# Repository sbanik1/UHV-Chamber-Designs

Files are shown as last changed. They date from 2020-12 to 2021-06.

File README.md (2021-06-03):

# UHV-Chamber-Designs
UHV Chamber Designs for Cold Atom Experiments.

## Need for ultra-high vacuum (UHV) for Cold Atom Experiments
The goal of an ultracold atomic physics experiment, is to produce quantum degenrate gases, for observing macroscopic effects of quantum statistics. This is possible when individual atomic wavepackets sufficiently overlap. The extent of these individual atomic wavepackets is given by the thermal de-broglie wavelength .

<p align="center">

</p>

For a given atomic species, the only way to increase  is by reducing the temperature. After the inital pre-cooling stages, the final cooling process for quantum degenerate gas production, is evaporative cooling. Atoms are evaporatively cooled by trapping them in magnetic traps or optical dipole traps. For **effective evaporative cooling**, one requires the collisional re-thermalization time to be much shorter than the lifetime of atoms in the trap [[1]](#1). In free space, atoms collide with background air particles and are ejected from the traps. This problem is solved by maintaing a vacuum of the order of  mbar.

## ErNa Vacuum Chamber Designs
This repo contains solidwork designs of the ErNa UHV chamber. Below are images of the full assembly.

<table>
  <tr>
    <td>
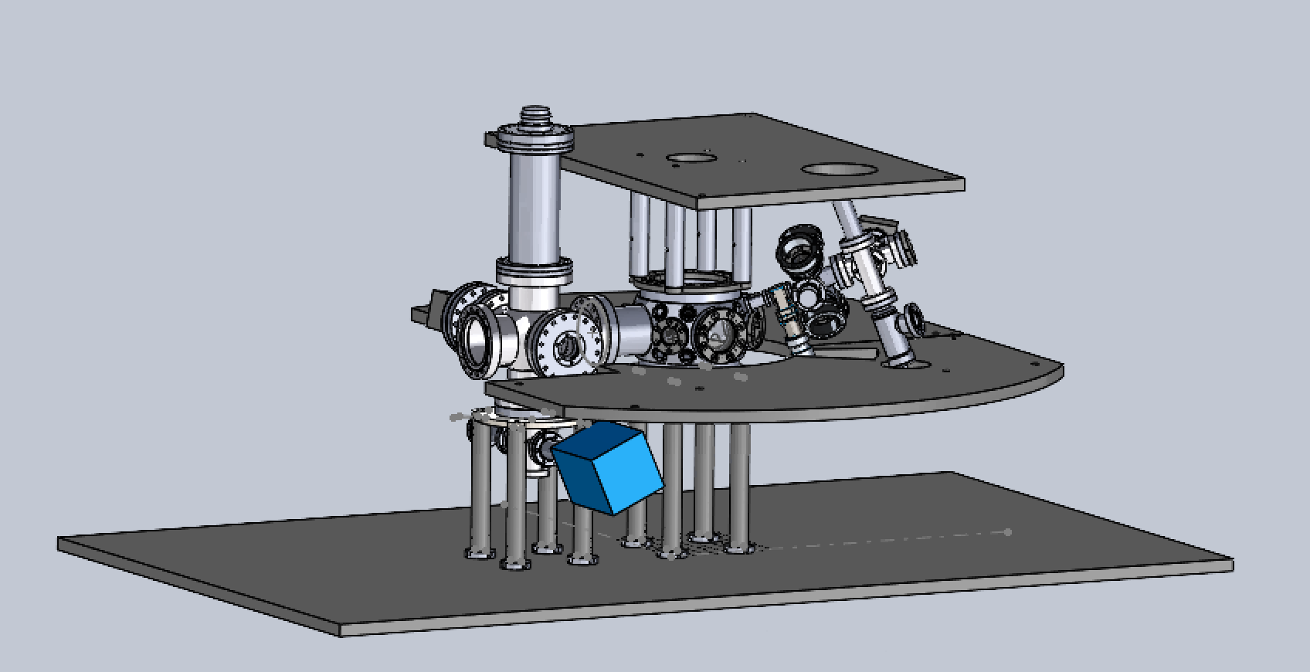
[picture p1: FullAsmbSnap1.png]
      </td>
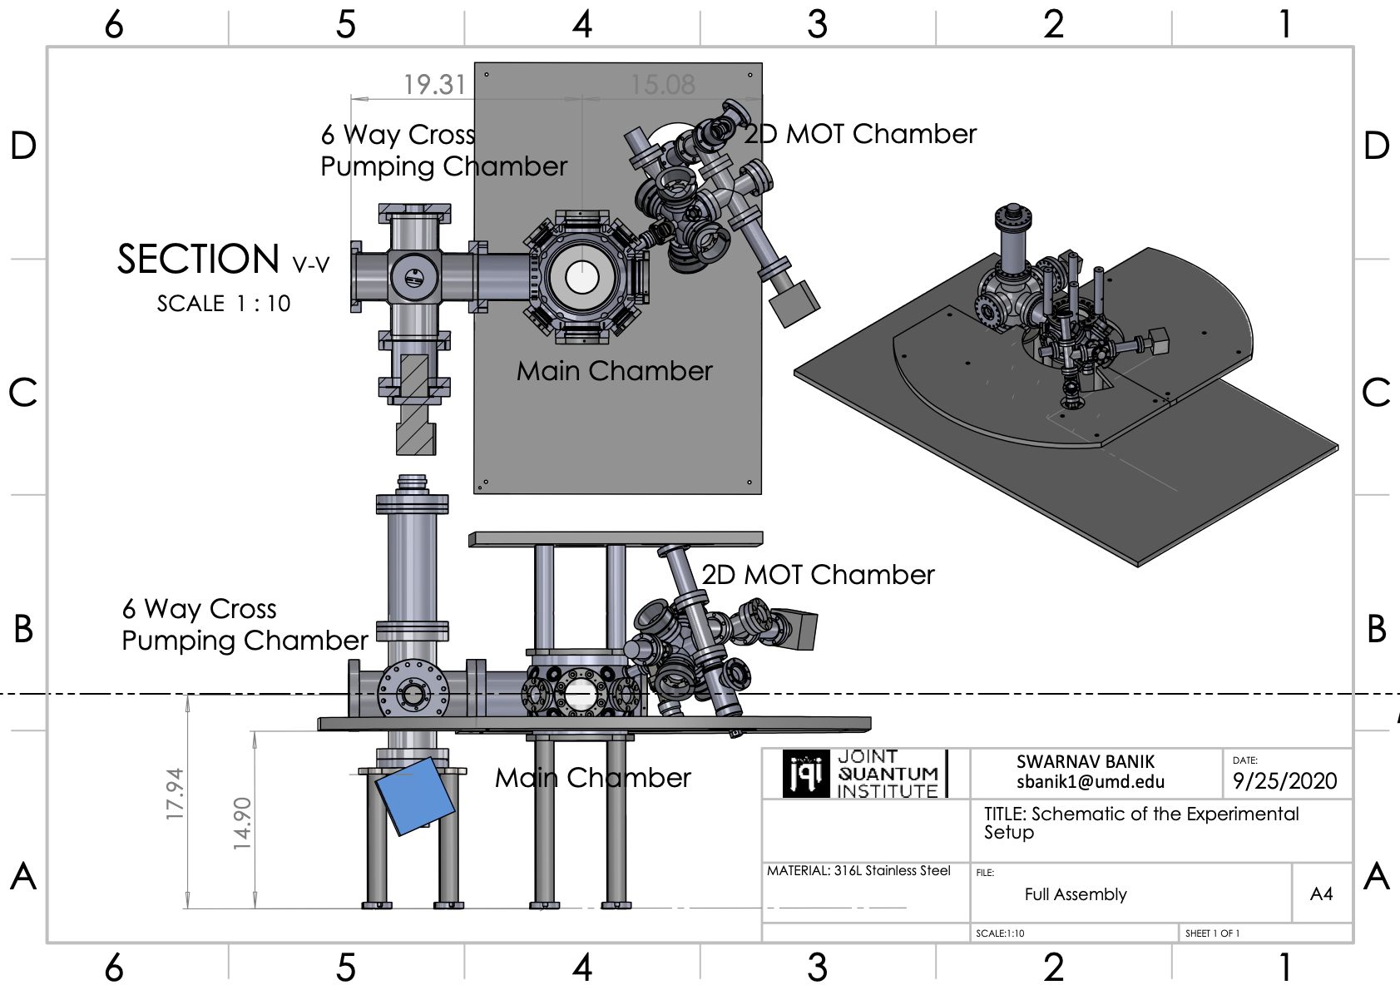
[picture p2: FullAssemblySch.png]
    <td></td>
  </tr>
</table>

### Overview of the different parts
All the science happens in the main chamber where sodium atoms are cooled down to a BEC. The sodium vapour is generated in the 2D MOT chamber where it is pre-cooled before being sent over to the main chamber. The pumping elements for the main chamber are attached to the 6 way cross connected to the main chamber. The main chamber and the 2D MOT are maintained at different pressures. The 2D MOT chamber has the atomic source which needs to heated to high temperatures. As a result, it is not possible to maintain UHV pressures in this chamber. So the 2D MOT chmaber and Main chamber are separated by a differential pumping tube. Below is the schematic of the differential pumping tube used.

<table>
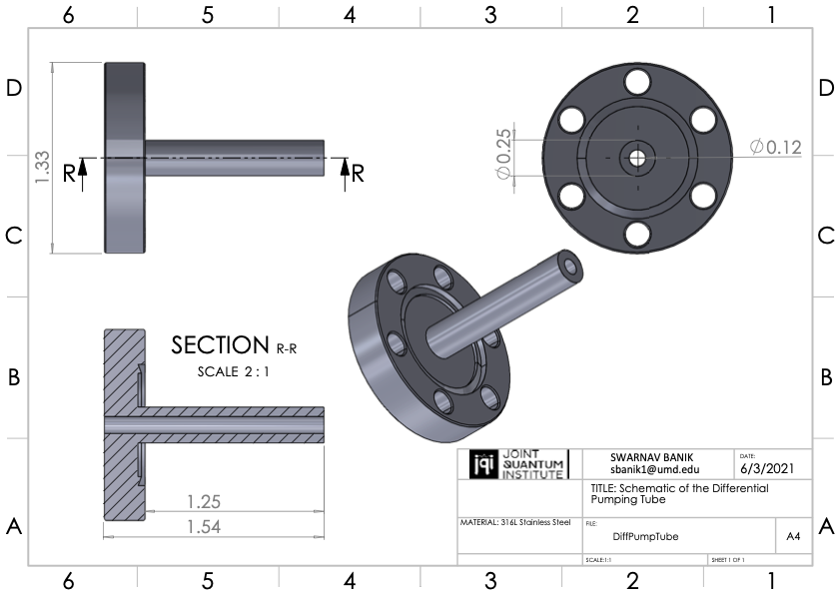
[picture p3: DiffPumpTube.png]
  <tr><td align="center"></td></tr>
</table>

<table>
  <tr>
    <td align="center">
      Main Chamber
    </td>
    <td align="center">
      2D Magneto Optical trap (2D MOT)
    </td>
    <td  align="center">
      6 Way Cross Setup
    </td>
  </tr>
  <tr>
    <td>
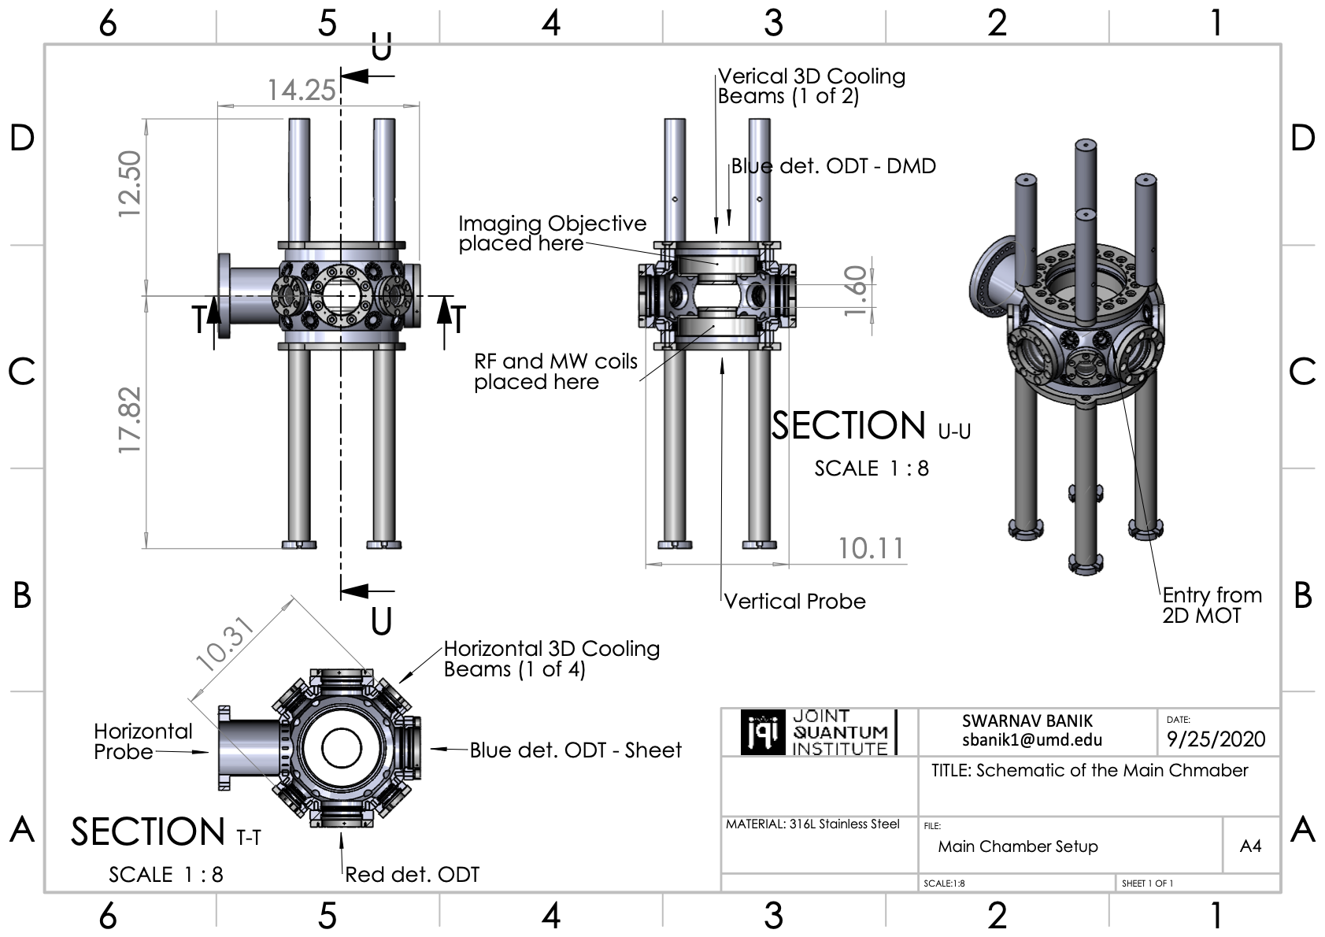
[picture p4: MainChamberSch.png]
      
    </td>
    <td>
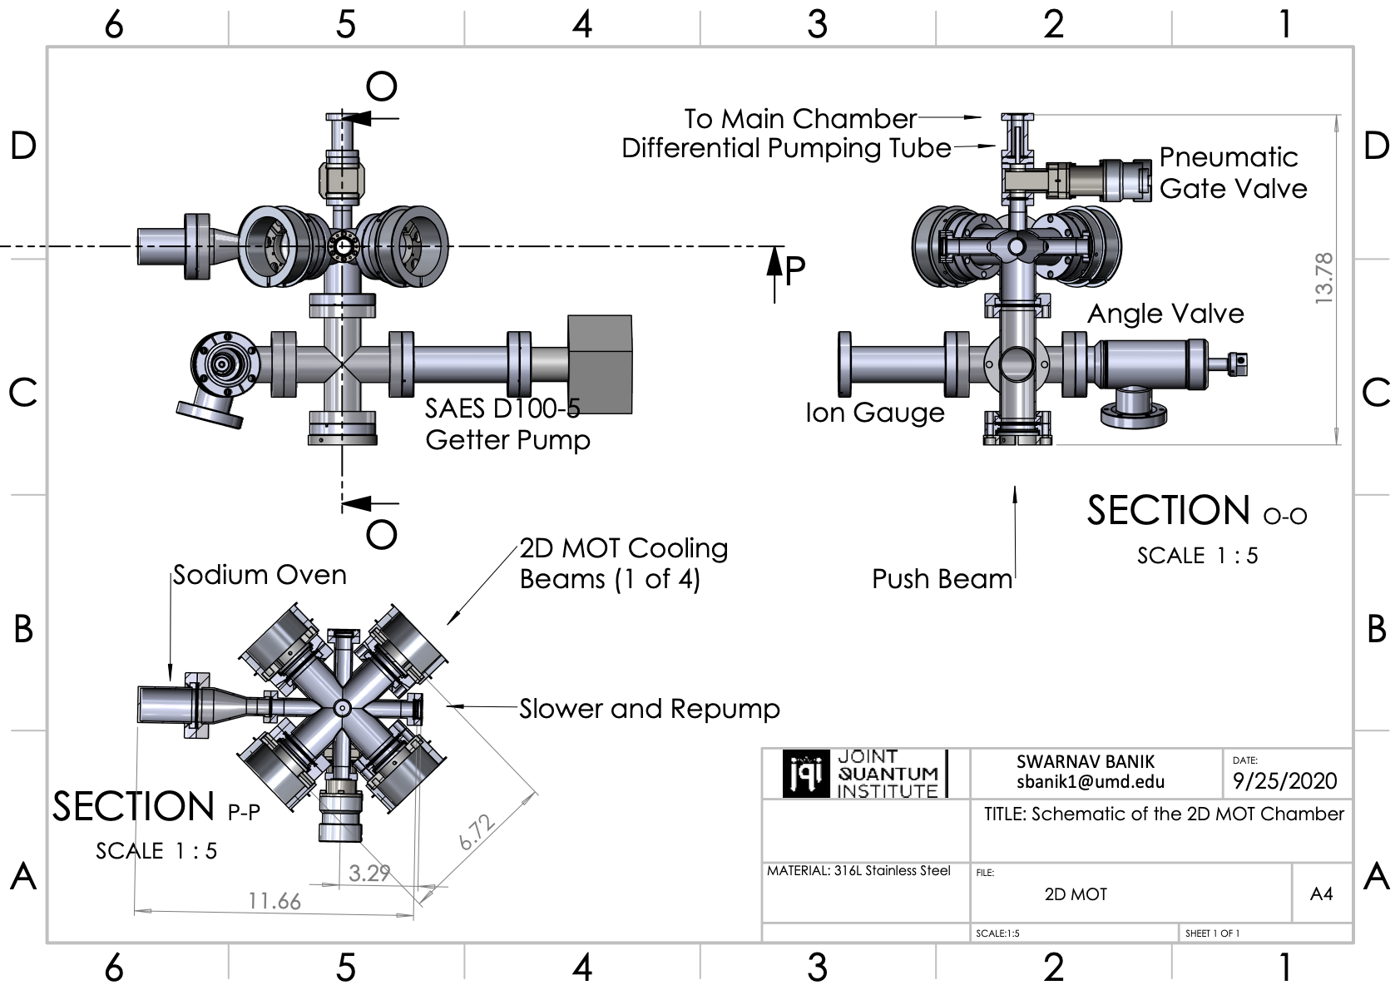
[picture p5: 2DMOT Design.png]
      
    </td>
    <td>
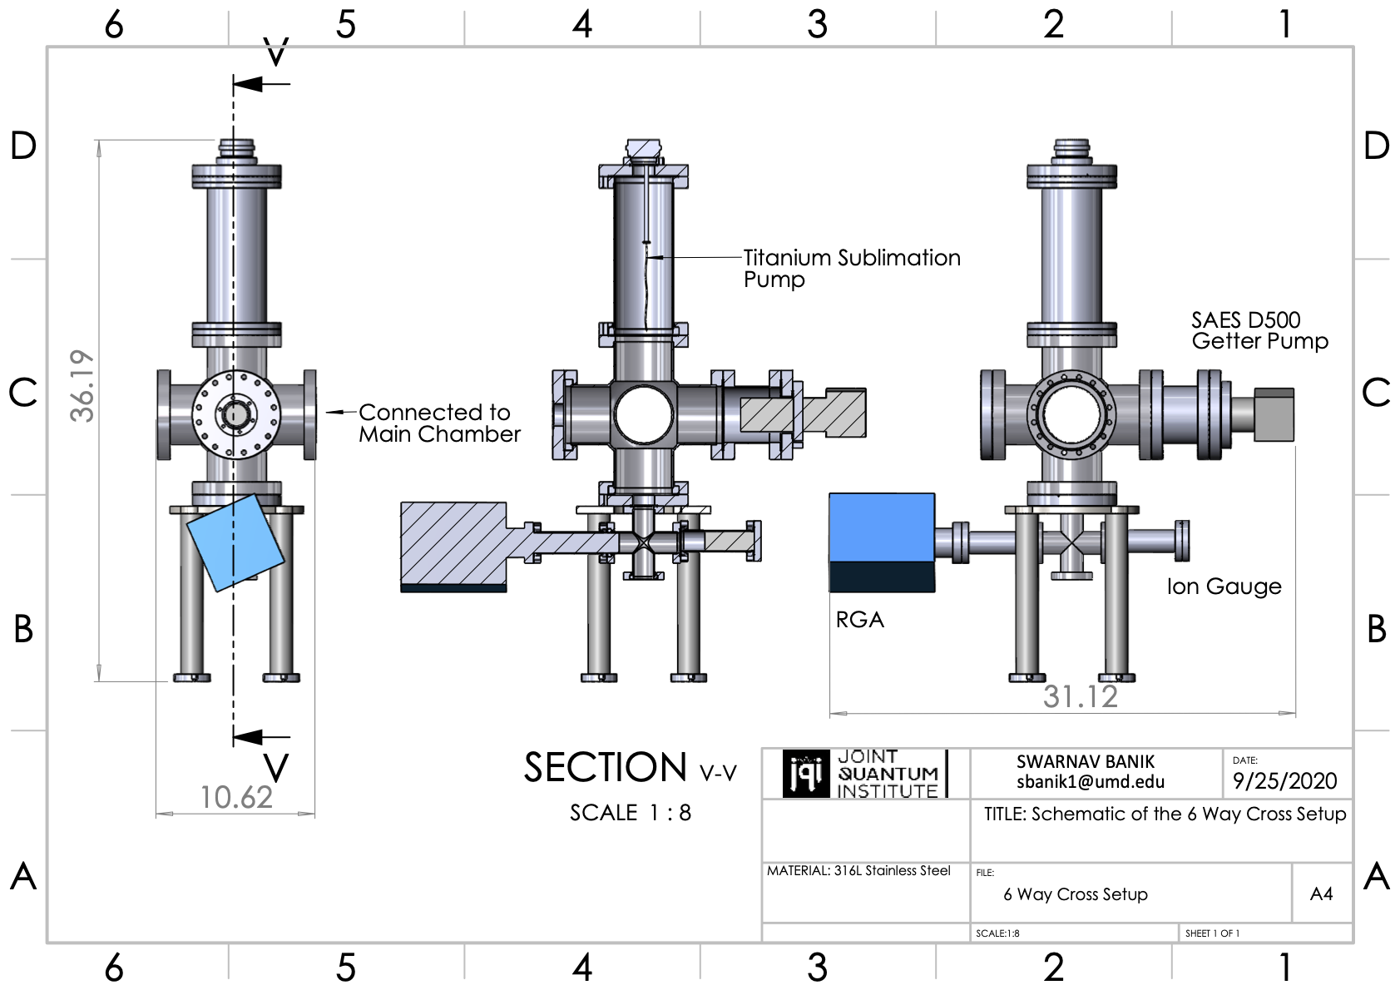
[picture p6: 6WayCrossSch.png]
      
    </td>
  </tr>
</table>

### Improvements from Traditional Zeeman Slowers
<table>
  <tr>
    <td align="center">
      Chamber with Zeeman Slower [2]
    </td>
    <td align="center">
      Chamber with 2D MOT
    </td>
  </tr>
  <tr>
    <td>
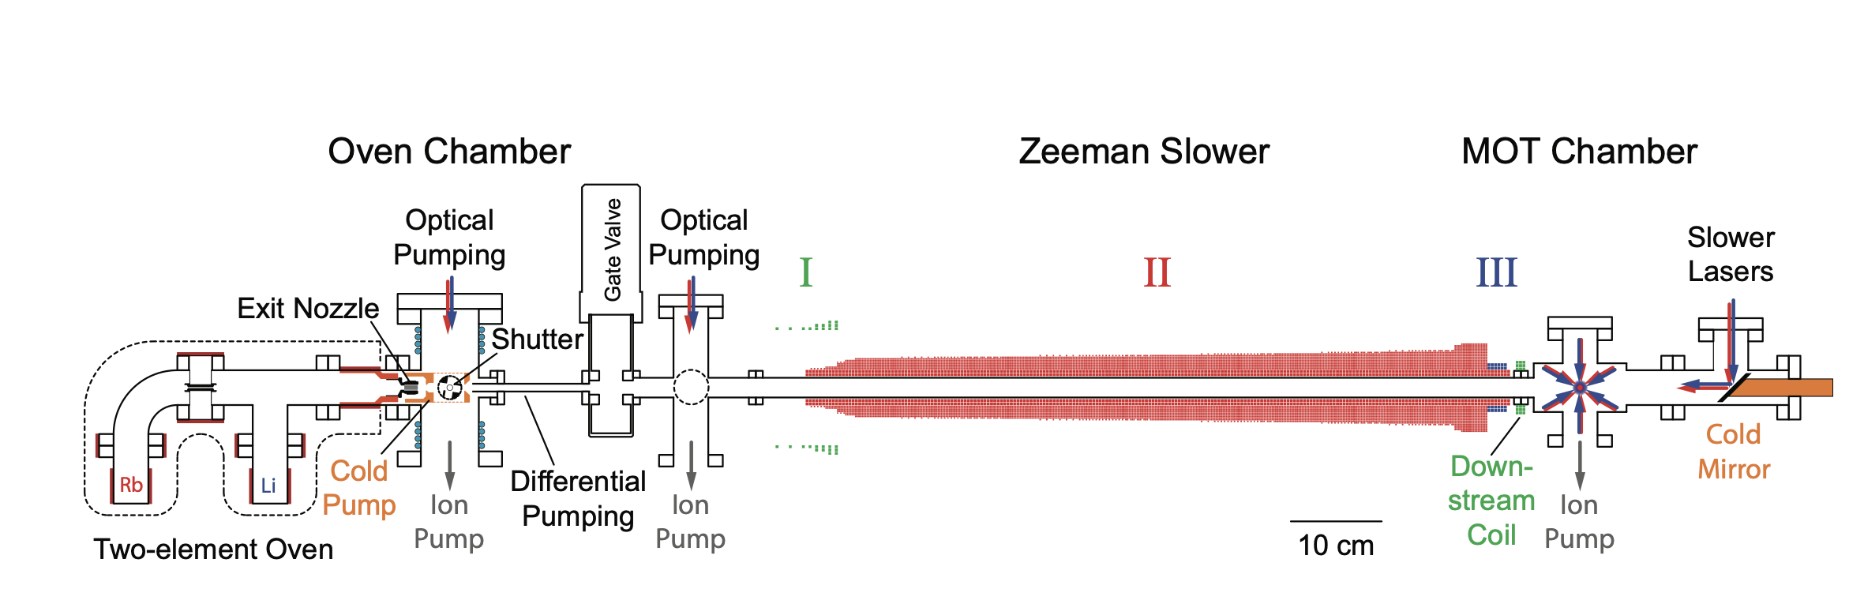
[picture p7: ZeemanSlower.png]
      
    </td>
    <td>
      
    </td>
  </tr>
</table>

The image to the left is a typical Zeeman slower [[2]](#2). Zeeman slowers are about 1m long. Our 2D MOT is atleast 3 times shorter.

## References
<a id="1">[1]</a> 
W. Keterlee, D.S. Durfee, and D.M. Stamper-Kurn (Apr. 5, 1999). 
Making, probing and understanding Bose-Einstein condensates. 
arXiv:cond-mat/9904034v2 

<a id="2">[2]</a> 
G. Edward Marti, Ryan Olf, Enrico Vogt, Anton Öttl, and Dan M. Stamper-Kurn (Apr., 2010). 
Two-element Zeeman slower for rubidium and lithium. 
Phys. Rev. A,81,043424

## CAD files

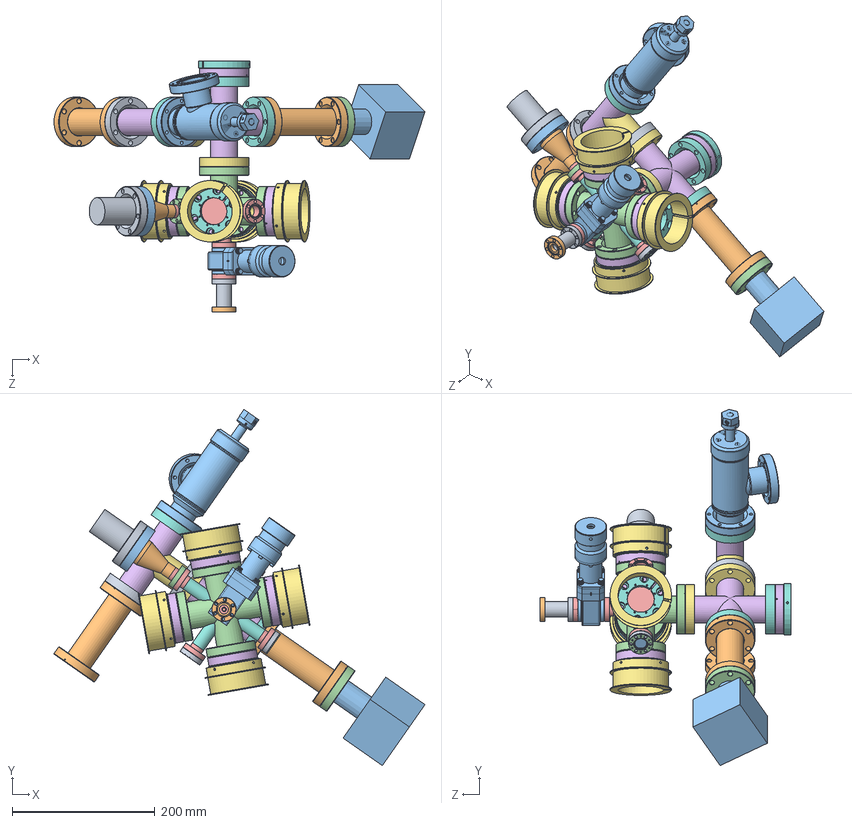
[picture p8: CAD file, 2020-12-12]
2D MOT/2D MOT.SLDASM
518.9 x 498.2 x 351.4 mm
Cup
110014 (2.75 X 1.5 NR)
100004 (1.33 X .75 REC)
100004 (1.33 X .75 INS)
405002 P1_405002-001 x 2
405002 P2_110014 (2.75 X 1.5 NR)_1 x 2
405002 P4_100014 (2.75 X 1.5 REC)_1 x 2
405002 P5_100014 (2.75 X 1.5 INS)_1 x 2
2D MOT nipple_402002 rev A x 2
2D MOT Pump outer
2D MOT Pump conflat_110008
2D MOT Pump inner
404002 P5_404002-001
404002 P6_404002-002
404002 P4_110014 (2.75 X 1.5 NR)_1
404002 P3_100014 (2.75 X 1.5 REC) x 2
404002 P1_100014 (2.75 X 1.5 INS) x 2
Angle Valve_314003
5way MDC-406002-mine
MiniFlange-weld-mine x 5
ChamberTube
CameraTube
OvenTube x 3
Connection Nipple P1_110000
Connection Nipple P2_110000
Gate Valve 302000
2.75 Window P1-1 x 5
2.75 Window P1-2 x 5
2.75 Window P2 x 5
Coil mount x 4
Viewport Washer 2.75 x 5
0784101L x 2
0194307B x 2
1002201A x 2
Viewport Washer 1.33 x 2
DiffPumpTube

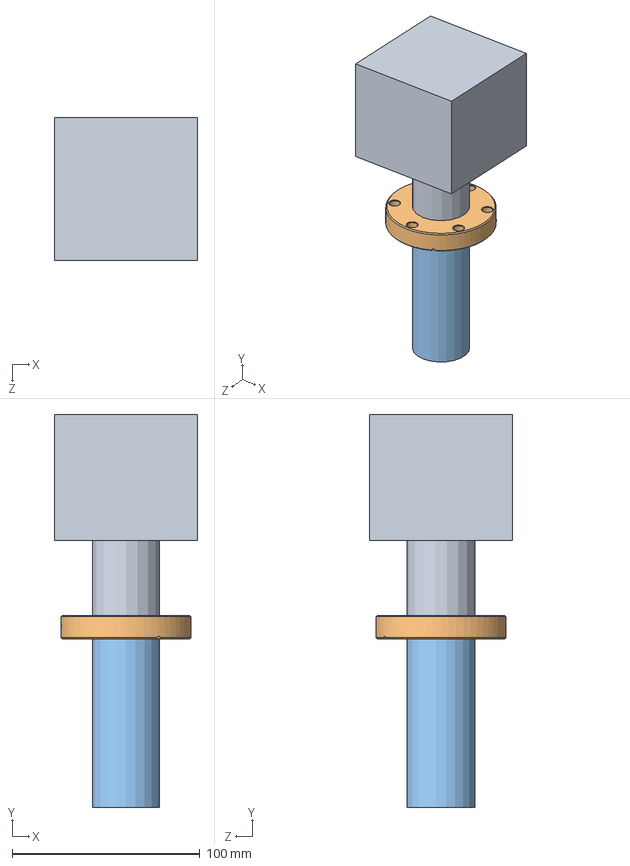
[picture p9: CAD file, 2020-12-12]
2D MOT/SAES Getter_D100-5/2D MOT Pump.SLDASM
76.2 x 209.3 x 76.2 mm
2D MOT Pump outer
2D MOT Pump conflat_110008
2D MOT Pump inner

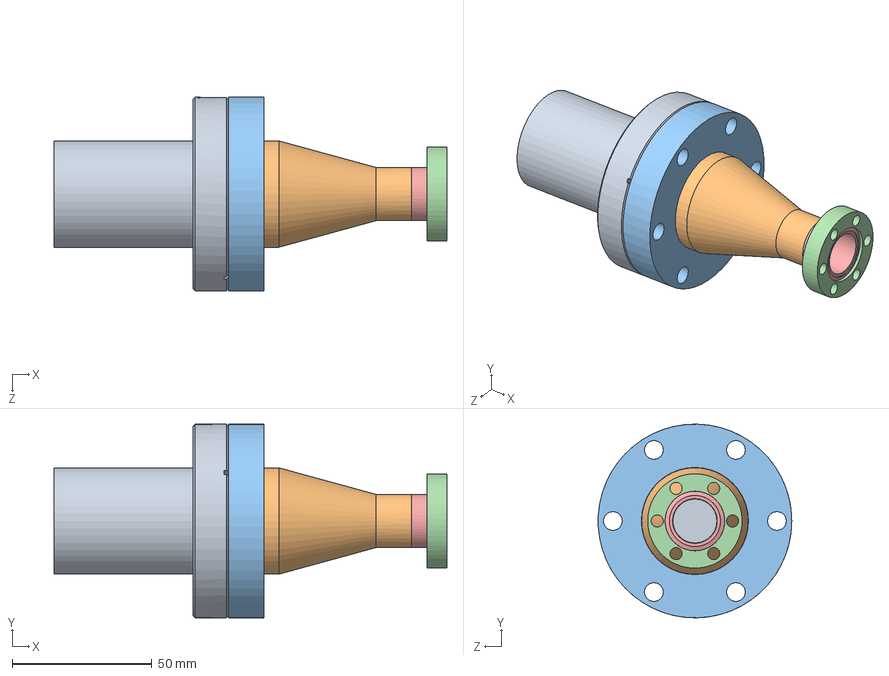
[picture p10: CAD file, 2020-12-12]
2D MOT/Sodium Oven/Na Oven.SLDASM
140.7 x 69.3 x 69.3 mm
Cup
110014 (2.75 X 1.5 NR)
100004 (1.33 X .75 REC)
100004 (1.33 X .75 INS)

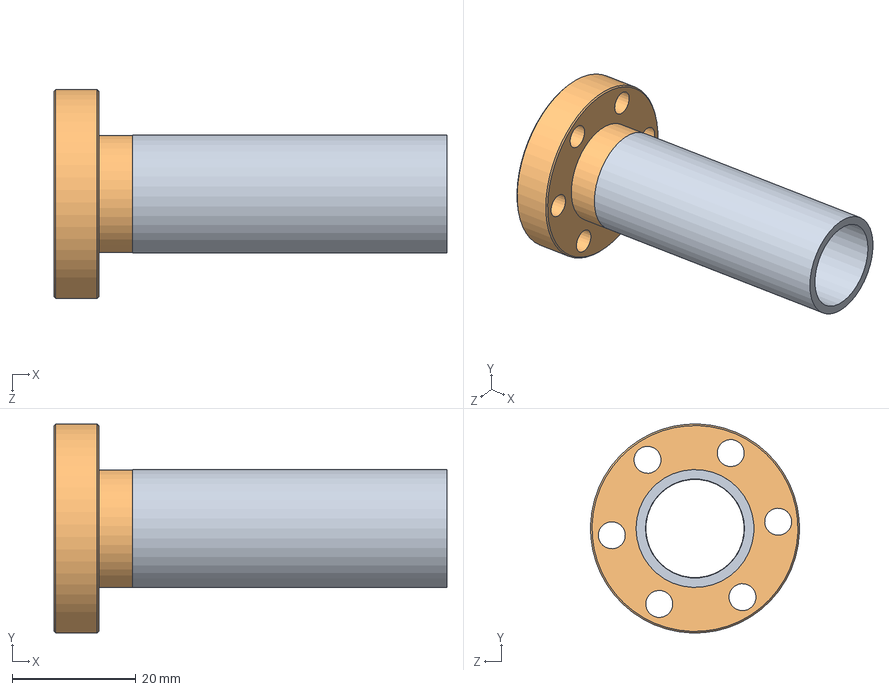
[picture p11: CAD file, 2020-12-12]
2D MOT/Tenway Cross/ Camera Assembly.SLDASM
63.5 x 33.8 x 33.8 mm
CameraTube
MiniFlange-weld-mine

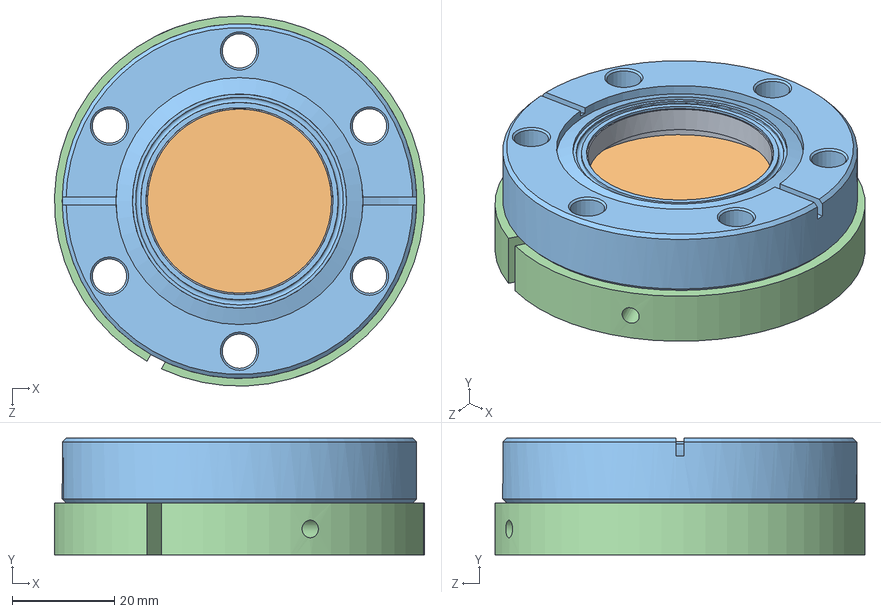
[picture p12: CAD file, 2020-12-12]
Main Chamber/2.75 VP Assembly/2.75 VP Assembly.SLDASM
72.4 x 22.9 x 72.4 mm
2.75 Window P1-1
2.75 Window P1-2
2.75 Window P2
Viewport Washer 2.75

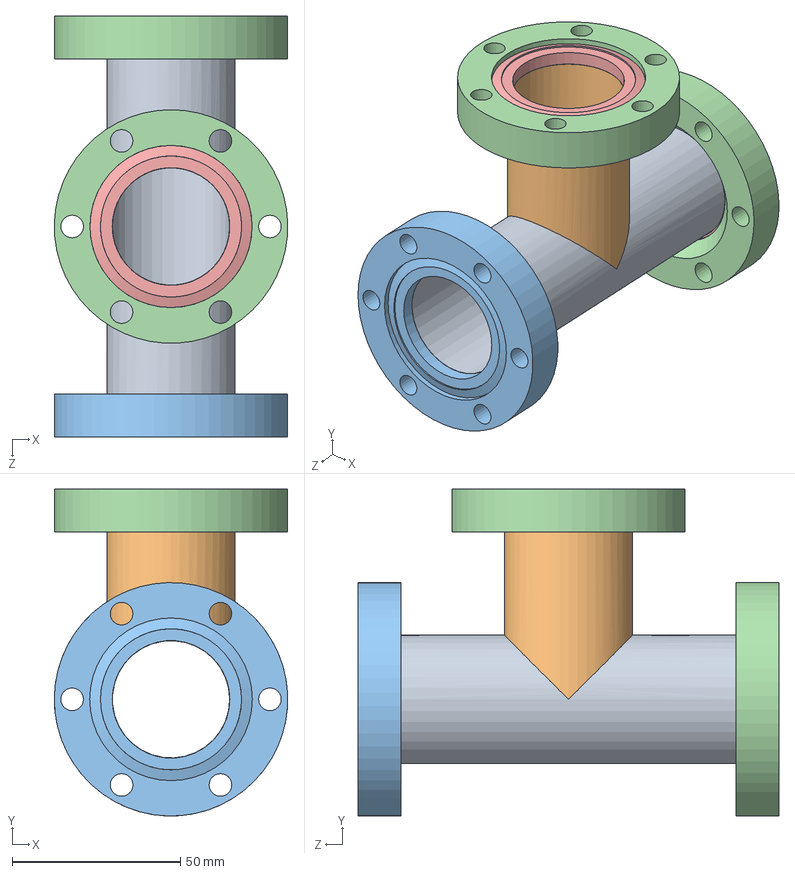
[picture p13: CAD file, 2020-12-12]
Main Chamber/2.75 VP Assembly/2.75 Window/2D MOT tee_404002.SLDASM
69.3 x 97.1 x 124.9 mm
404002 P5_404002-001
404002 P6_404002-002
404002 P4_110014 (2.75 X 1.5 NR)_1
404002 P3_100014 (2.75 X 1.5 REC) x 2
404002 P1_100014 (2.75 X 1.5 INS) x 2

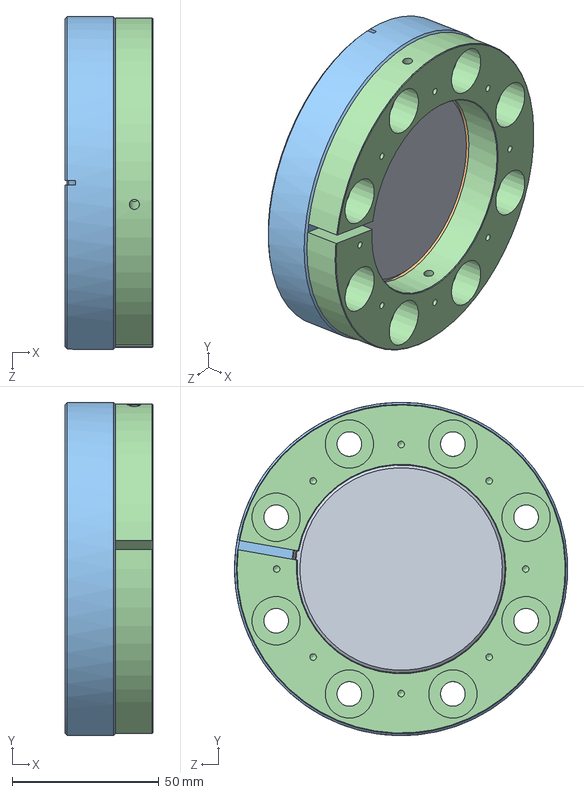
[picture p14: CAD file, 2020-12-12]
Main Chamber/4.5 VP Assembly/4.5 VP Assembly.SLDASM
30.0 x 113.5 x 113.4 mm
1002203A
Viewport 4.5 P1_0194302B
Viewport 4.5 P2_0194603B
Viewport Washer 4.5

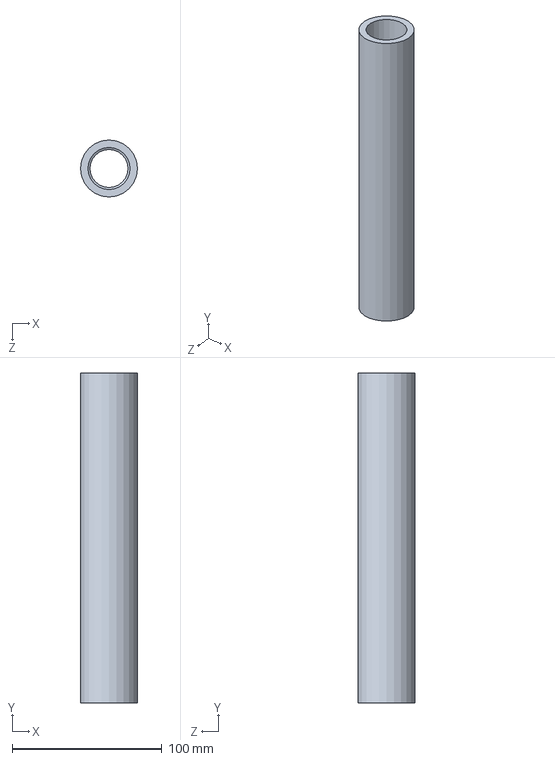
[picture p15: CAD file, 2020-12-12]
Main Chamber/Damped Post Main Chamber/Damped Post for Main Chamber Top P1.SLDPRT
38.1 x 220.5 x 38.1 mm

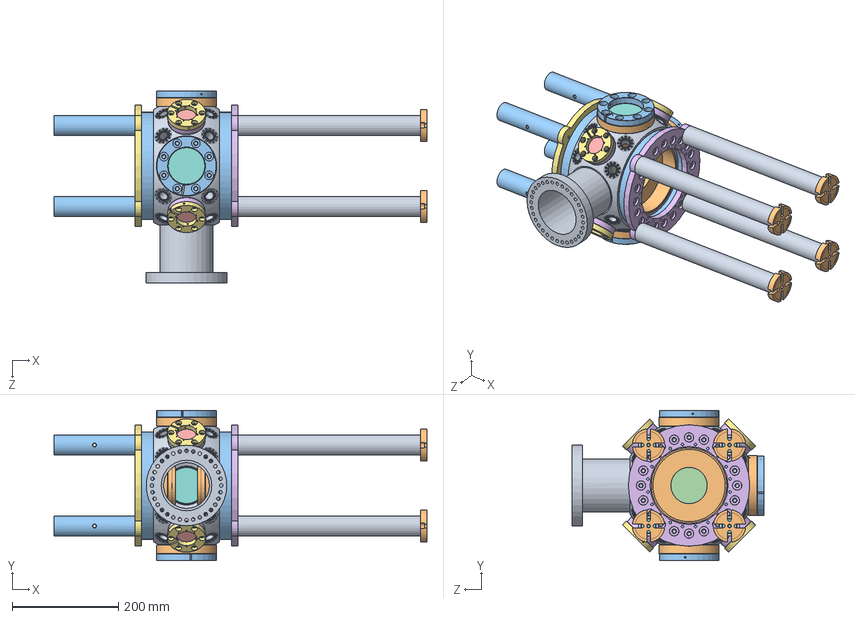
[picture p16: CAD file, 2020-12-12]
Main Chamber/Main Chamber Setup.SLDASM
702.1 x 283.0 x 362.2 mm
Modified Kimball Chamber
ISAdaptor x 2
ISFlange x 2
ISWindow x 2
RecessedRing x 2
Washer Chamber Base
Washer Chamber Top
Damped Post for Main Chamber P2_90322A235 x 8
Damped Post for Main Chamber Bottom P1 x 4
Damped Post for Main Chamber P3_PB2 x 4
Chamber Top Post_P6 x 4
2.75 Window P1-1 x 4
2.75 Window P1-2 x 4
2.75 Window P2 x 4
Viewport Washer 2.75 x 4
1002203A x 3
Viewport 4.5 P1_0194302B x 3
Viewport 4.5 P2_0194603B x 3
Viewport Washer 4.5 x 3

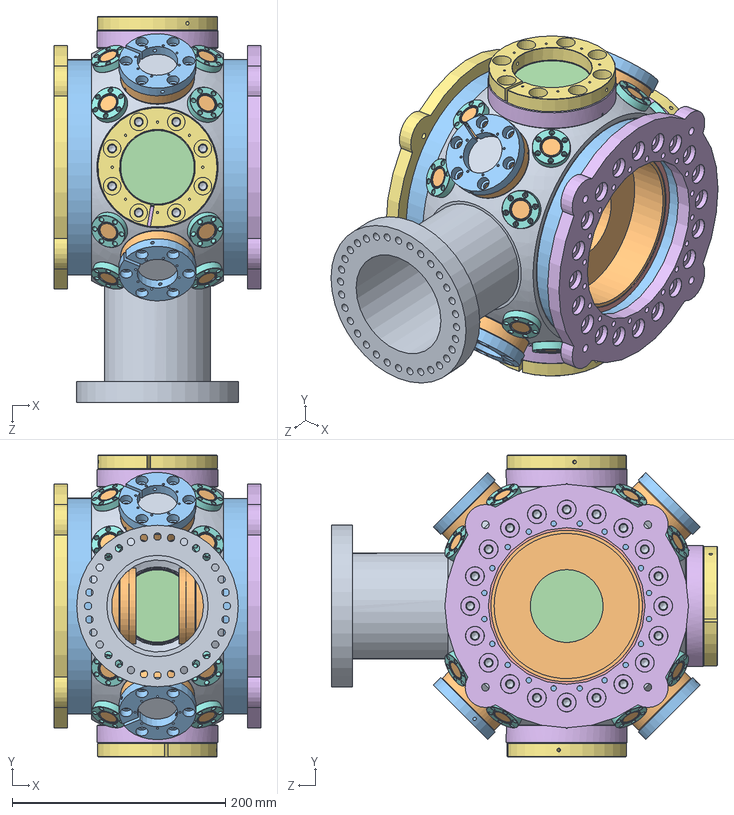
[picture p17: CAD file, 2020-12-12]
Main Chamber/VP distances/Main Chamber VP only .SLDASM
194.1 x 283.0 x 362.2 mm
Modified Kimball Chamber
ISAdaptor x 2
ISFlange x 2
ISWindow x 2
RecessedRing x 2
Washer Chamber Base
Washer Chamber Top
2.75 Window P1-1 x 4
2.75 Window P1-2 x 4
2.75 Window P2 x 4
Viewport Washer 2.75 x 4
1002203A x 3
Viewport 4.5 P1_0194302B x 3
Viewport 4.5 P2_0194603B x 3
Viewport Washer 4.5 x 3
0784101L x 16
0194307B x 16
1002201A x 16

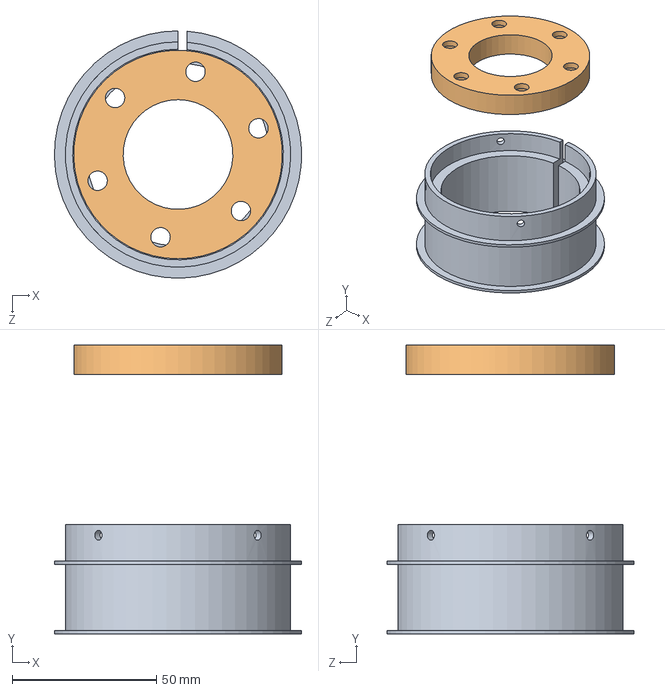
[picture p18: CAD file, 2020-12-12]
2D MOT/2DMOT Bias Coils/Assembly.SLDASM
85.8 x 100.3 x 85.8 mm
Coil mount
Viewport Washer 2.75

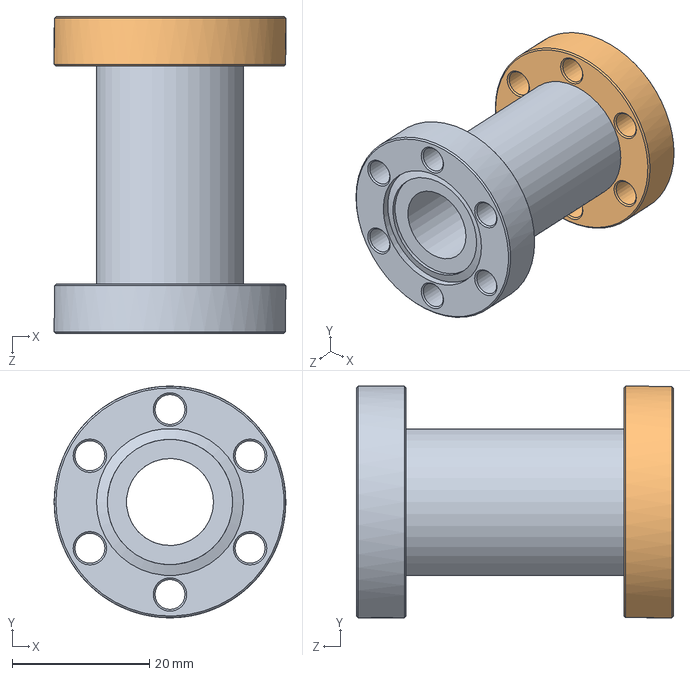
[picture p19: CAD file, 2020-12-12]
2D MOT/Connection nipple/Connection Nipple.SLDASM
33.8 x 33.8 x 46.2 mm
Connection Nipple P1_110000
Connection Nipple P2_110000

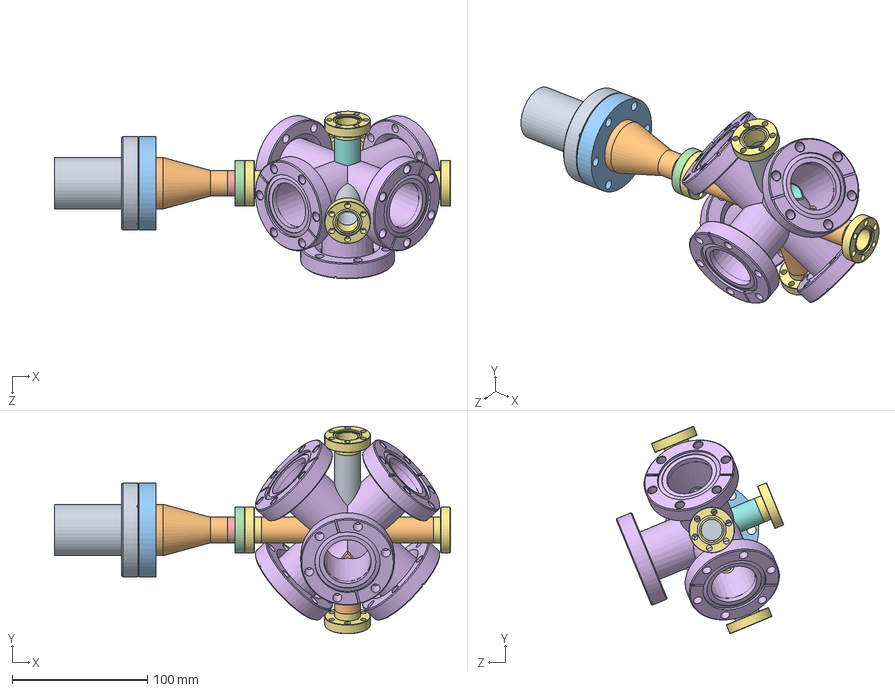
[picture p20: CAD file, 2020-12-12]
2D MOT/Tenaway with Na Oven.SLDASM
293.1 x 153.5 x 124.0 mm
Cup
110014 (2.75 X 1.5 NR)
100004 (1.33 X .75 REC)
100004 (1.33 X .75 INS)
5way MDC-406002-mine
MiniFlange-weld-mine x 5
ChamberTube
CameraTube
OvenTube x 3

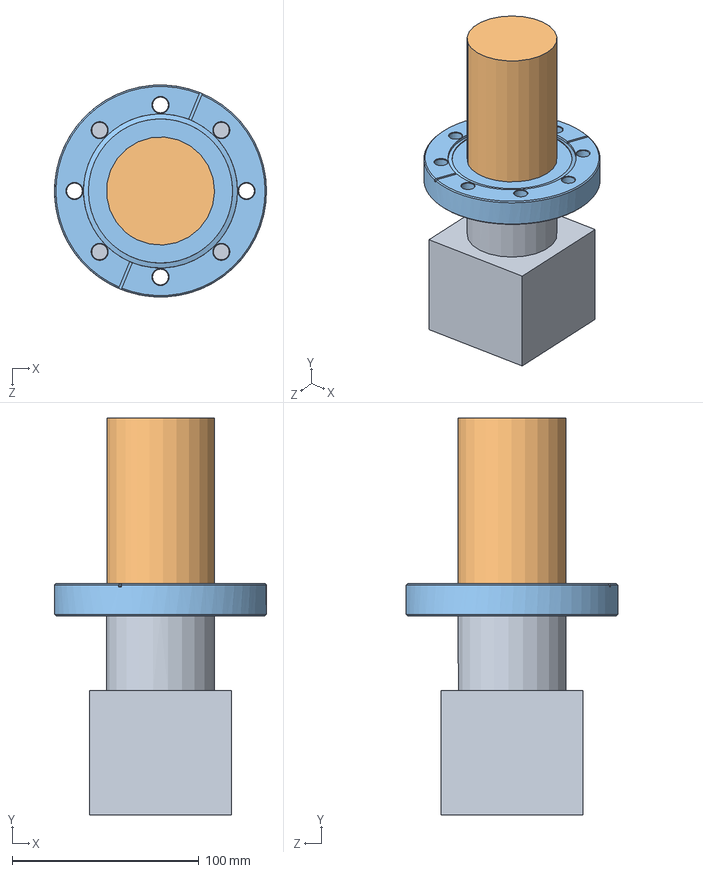
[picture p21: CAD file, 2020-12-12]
6 Way Cross Setup/6 Way Cross Getter SAES D-500/6WayPump.SLDASM
113.5 x 212.6 x 113.5 mm
6WayPump outer
6WayPump inner
6WayPump conflat

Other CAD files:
6 Way Cross Setup/6 way cross setup.SLDASM
Main Chamber/Bucket Window/Bucket Window.SLDASM
Main Chamber/Mini lens stack holder/1.33 Viewport/1.33 Viewport.SLDASM
2D MOT/Conical Adapter 1.33-2.75/Conical Adapter 1.33-2.75.SLDASM
2D MOT/1.33 Window/0194307B.sldprt
2D MOT/1.33 Window/0784101L.sldprt
2D MOT/1.33 Window/0784301N.sldasm
2D MOT/1.33 Window/1002201A.sldprt
2D MOT/1.33 Window/9722013.STEP
2D MOT/1.33 Window/VP_1.33.SLDASM
2D MOT/2.75 Four Way Cross/2.75 Four Way Cross.SLDASM
2D MOT/2.75 Four Way Cross/405002 P1_100014 (2.75 X 1.5 INS).sldprt
2D MOT/2.75 Four Way Cross/405002 P1_405002-001.sldprt
2D MOT/2.75 Four Way Cross/405002 P2_100014 (2.75 X 1.5 R).sldasm
2D MOT/2.75 Four Way Cross/405002 P2_110014 (2.75 X 1.5 NR)_1.sldprt
2D MOT/2.75 Four Way Cross/405002 P3_100014 (2.75 X 1.5 R)_1.sldasm
2D MOT/2.75 Four Way Cross/405002 P3_100014 (2.75 X 1.5 REC).sldprt
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

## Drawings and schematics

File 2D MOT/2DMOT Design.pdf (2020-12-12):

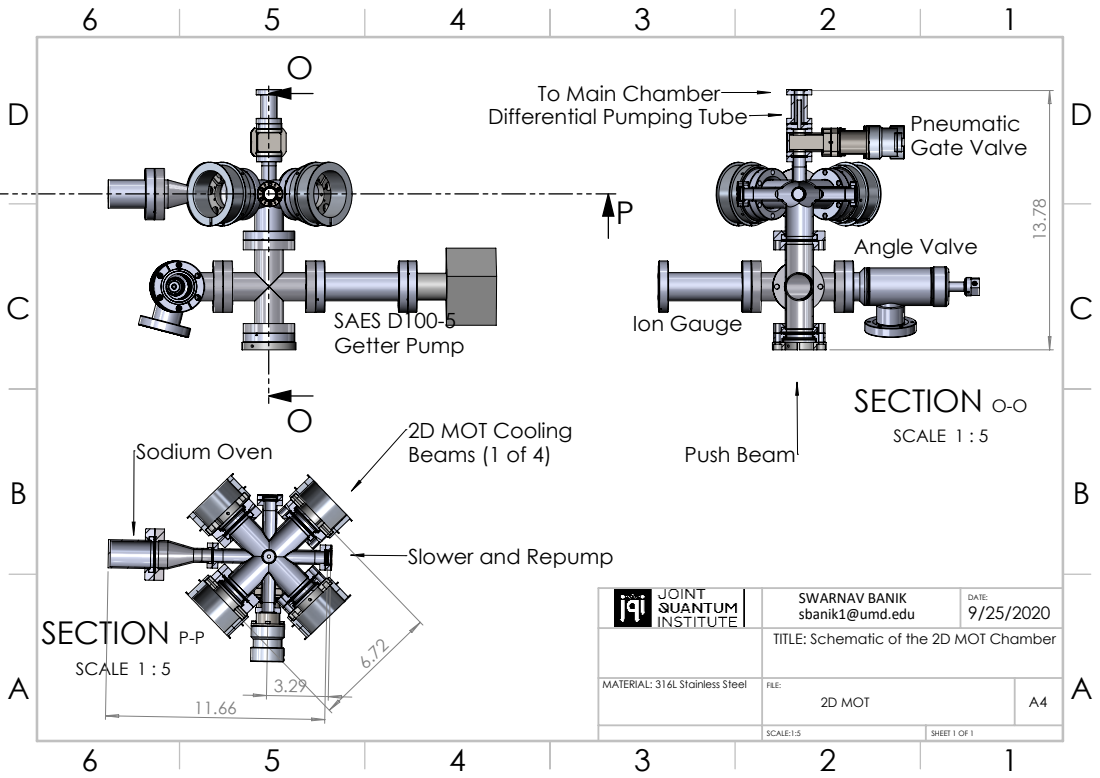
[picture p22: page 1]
SAES D100-5 Getter Pump; SECTION O-O; SCALE 1 : 5; Ion Gauge; Gate Valve; Angle Valve; SECTION P-P; Sodium Oven; Push Beam; 2D MOT Cooling Beams (1 of 4)

To Main Chamber
Differential Pumping Tube

Slower and Repump

SWARNAV BANIK sbanik1@umd.edu | DATE: 9/25/2020

TITLE: Schematic of the 2D MOT Chamber

MATERIAL: 316L Stainless Steel | FILE: 2D MOT | A4

SCALE:1:5 | SHEET 1 OF 1

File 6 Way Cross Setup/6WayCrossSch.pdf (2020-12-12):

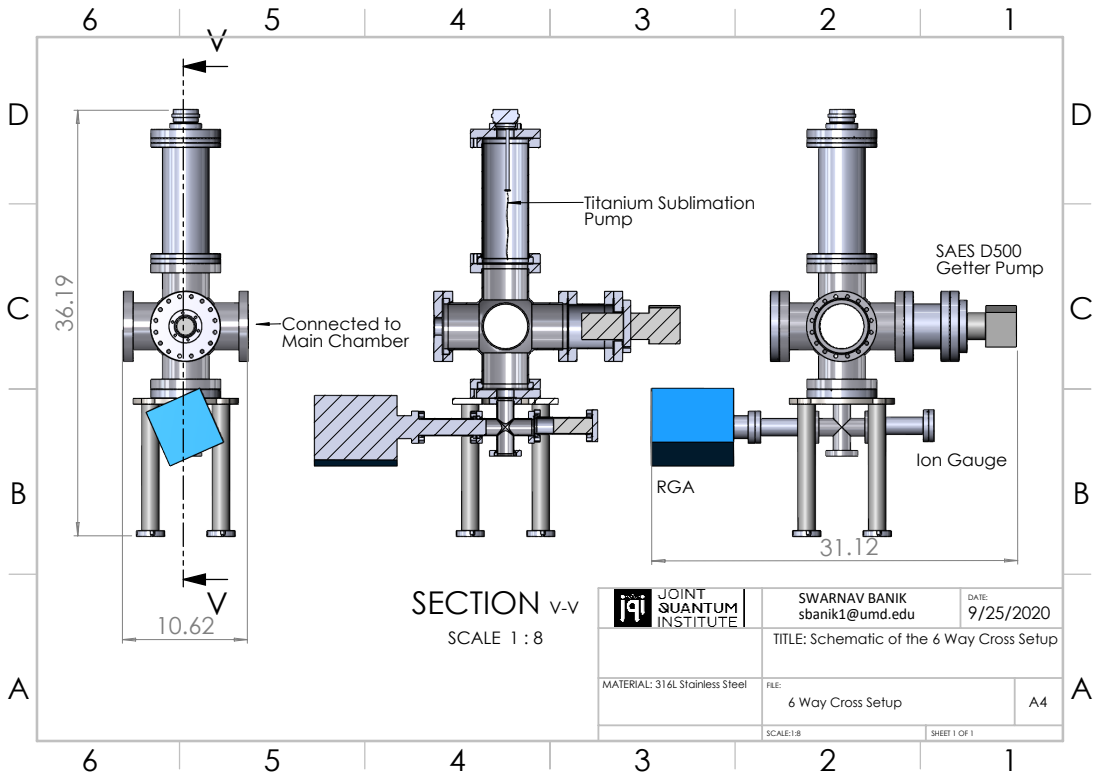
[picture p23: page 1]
Connected to Main Chamber; SAES D500 Getter Pump; Ion Gauge; SECTION V-V; SCALE 1 : 8; Titanium Sublimation

SWARNAV BANIK sbanik1@umd.edu | DATE: 9/25/2020

TITLE: Schematic of the 6 Way Cross Setup

MATERIAL: 316L Stainless Steel | FILE: 6 Way Cross Setup | A4

SCALE:1:8 | SHEET 1 OF 1

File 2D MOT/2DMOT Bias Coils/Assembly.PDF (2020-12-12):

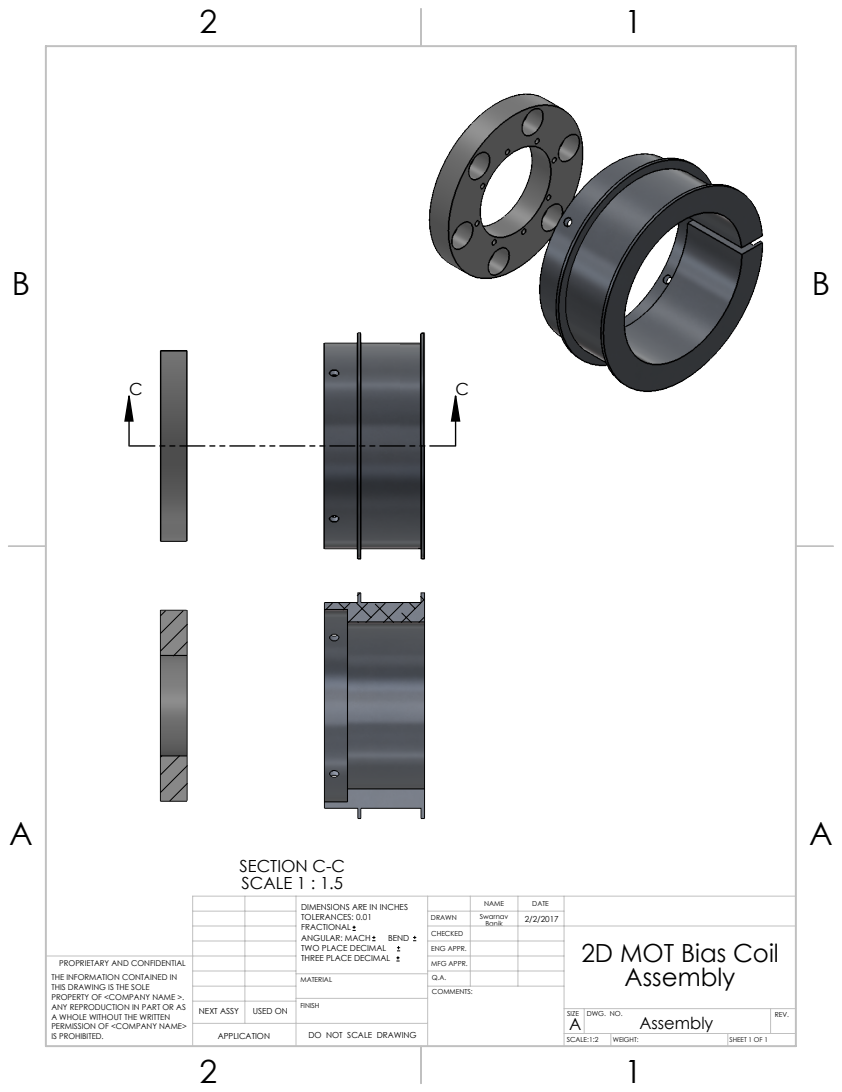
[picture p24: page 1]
SECTION C-C SCALE 1 : 1.5

TOLERANCES: 0.01 FRACTIONAL ANGULAR: MACH BEND TWO PLACE DECIMAL THREE PLACE DECIMAL | | NAME | DATE DIMENSIONS ARE IN INCHES | Assembly PROPRIETARY AND CONFIDENTIAL

DRAWN | Swarnav Banik | 2/2/2017
CHECKED | | | 2D MOT Bias Coil
ENG APPR.

THE INFORMATION CONTAINED IN THIS DRAWING IS THE SOLE PROPERTY OF <COMPANY NAME >. ANY REPRODUCTION IN PART OR AS A WHOLE WITHOUT THE WRITTEN PERMISSION OF <COMPANY NAME> IS PROHIBITED. | | | MFG APPR.

MATERIAL | Q.A.

NEXT ASSY | USED ON | FINISH

SIZE A | DWG. NO. Assembly | REV.

APPLICATION | | DO NOT SCALE DRAWING

SCALE:1:2 | WEIGHT: | SHEET 1 OF 1

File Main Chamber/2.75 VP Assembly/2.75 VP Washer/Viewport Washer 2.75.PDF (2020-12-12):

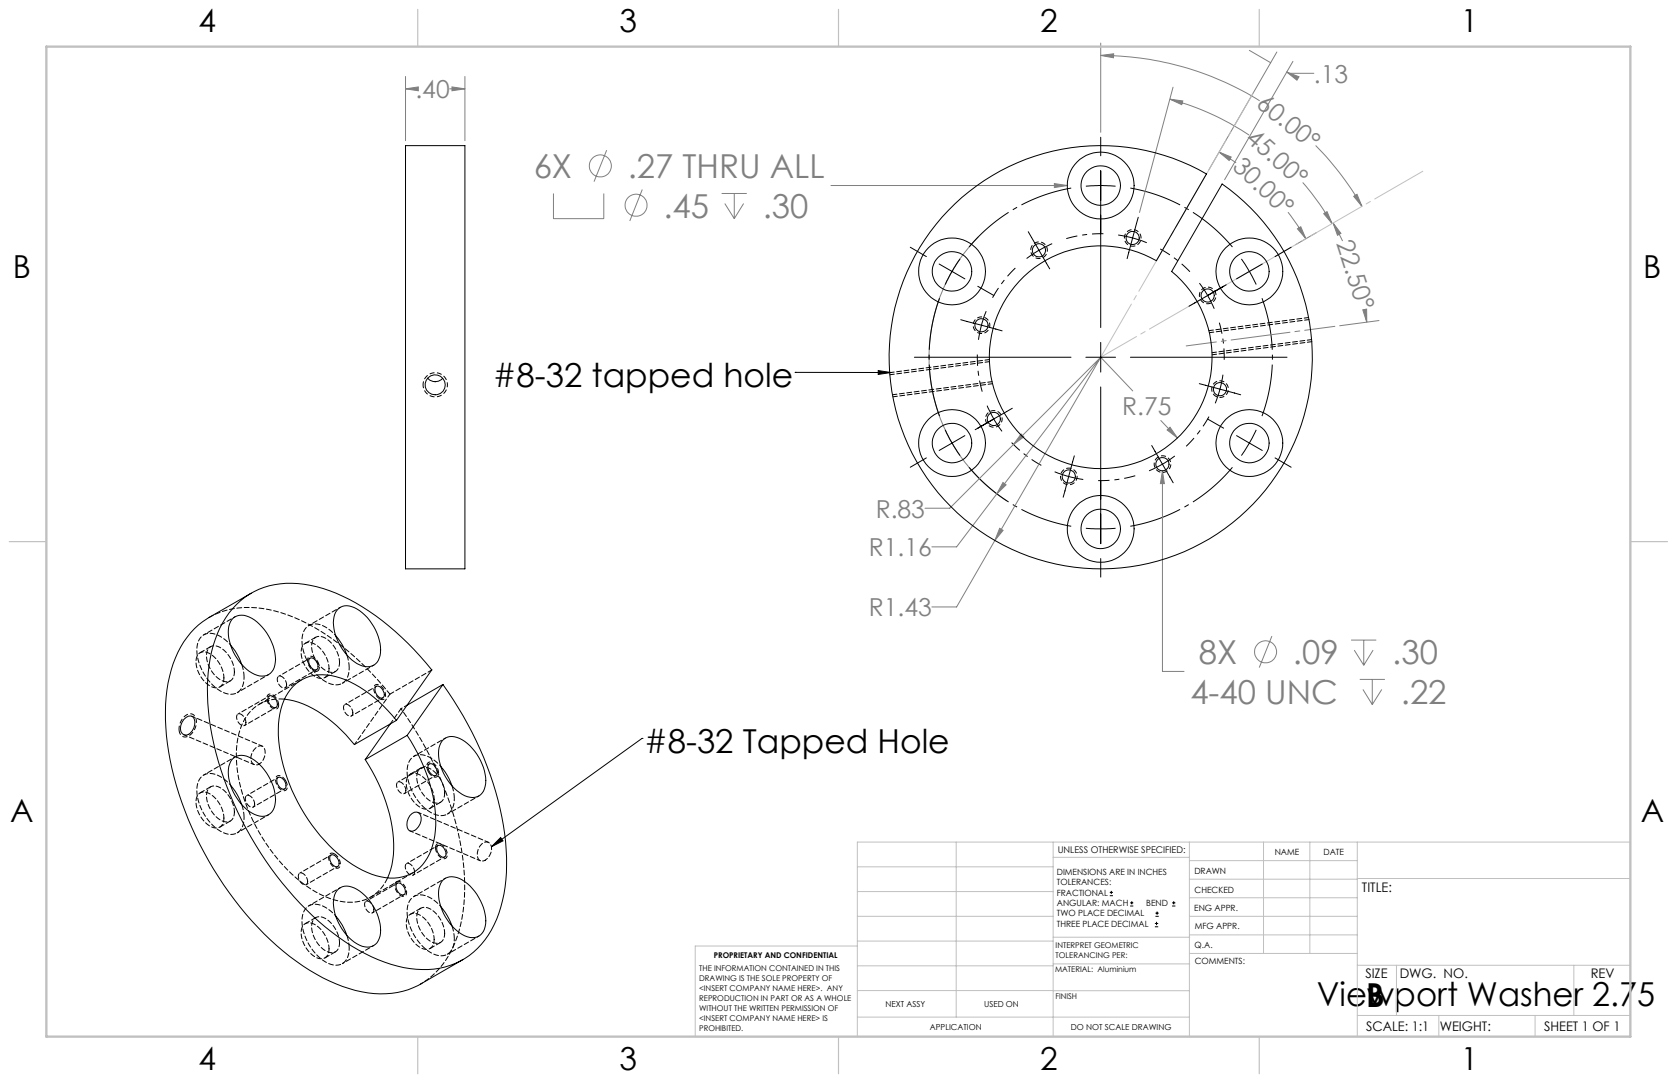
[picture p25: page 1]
.27 THRU ALL; 4-40 UNC; #8-32 tapped hole; #8-32 Tapped Hole; Viewport Washer 2.75

UNLESS OTHERWISE SPECIFIED: | | NAME | DATE
DIMENSIONS ARE IN INCHES TOLERANCES: FRACTIONAL ANGULAR: MACH BEND TWO PLACE DECIMAL THREE PLACE DECIMAL | DRAWN

CHECKED | | | TITLE:

ENG APPR.
MFG APPR.

INTERPRET GEOMETRIC TOLERANCING PER: | Q.A.
MATERIAL: Aluminium | | SIZE B | DWG. NO. | REV

PROPRIETARY AND CONFIDENTIAL
THE INFORMATION CONTAINED IN THIS
DRAWING IS THE SOLE PROPERTY OF
<INSERT COMPANY NAME HERE>. ANY
REPRODUCTION IN PART OR AS A WHOLE
WITHOUT THE WRITTEN PERMISSION OF
<INSERT COMPANY NAME HERE> IS
PROHIBITED.

NEXT ASSY | USED ON | FINISH

APPLICATION | DO NOT SCALE DRAWING | | SCALE: 1:1 | WEIGHT: | SHEET 1 OF 1

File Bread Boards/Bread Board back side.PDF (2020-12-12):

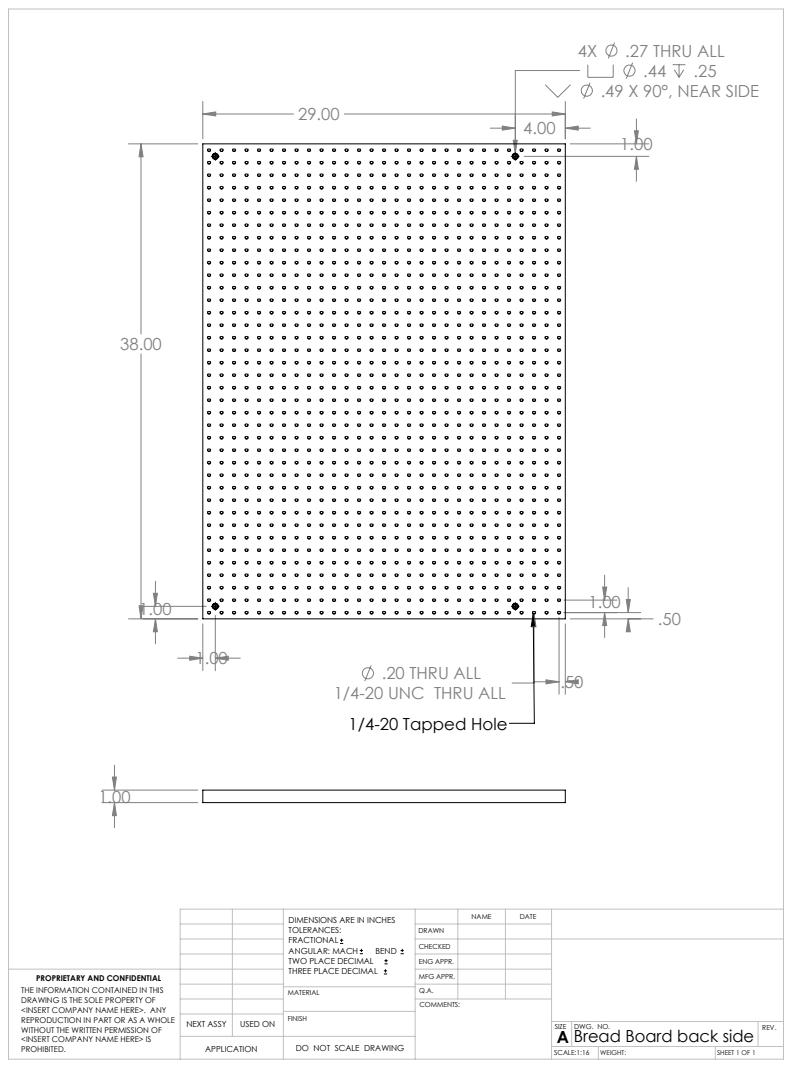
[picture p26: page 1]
.27 THRU ALL; .44 .25 .49 X 90°, NEAR SIDE

.20 THRU ALL
1/4-20 UNC THRU ALL
1/4-20 Tapped Hole

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

DRAWN
CHECKED
ENG APPR.

PROPRIETARY AND CONFIDENTIAL THE INFORMATION CONTAINED IN THIS DRAWING IS THE SOLE PROPERTY OF <INSERT COMPANY NAME HERE>. ANY REPRODUCTION IN PART OR AS A WHOLE WITHOUT THE WRITTEN PERMISSION OF <INSERT COMPANY NAME HERE> IS PROHIBITED. | | | MFG APPR.

MATERIAL | Q.A.

NEXT ASSY | USED ON | FINISH

SIZE A | DWG. NO. Bread Board back side | REV.

APPLICATION | | DO NOT SCALE DRAWING

SCALE:1:16 | WEIGHT: | SHEET 1 OF 1

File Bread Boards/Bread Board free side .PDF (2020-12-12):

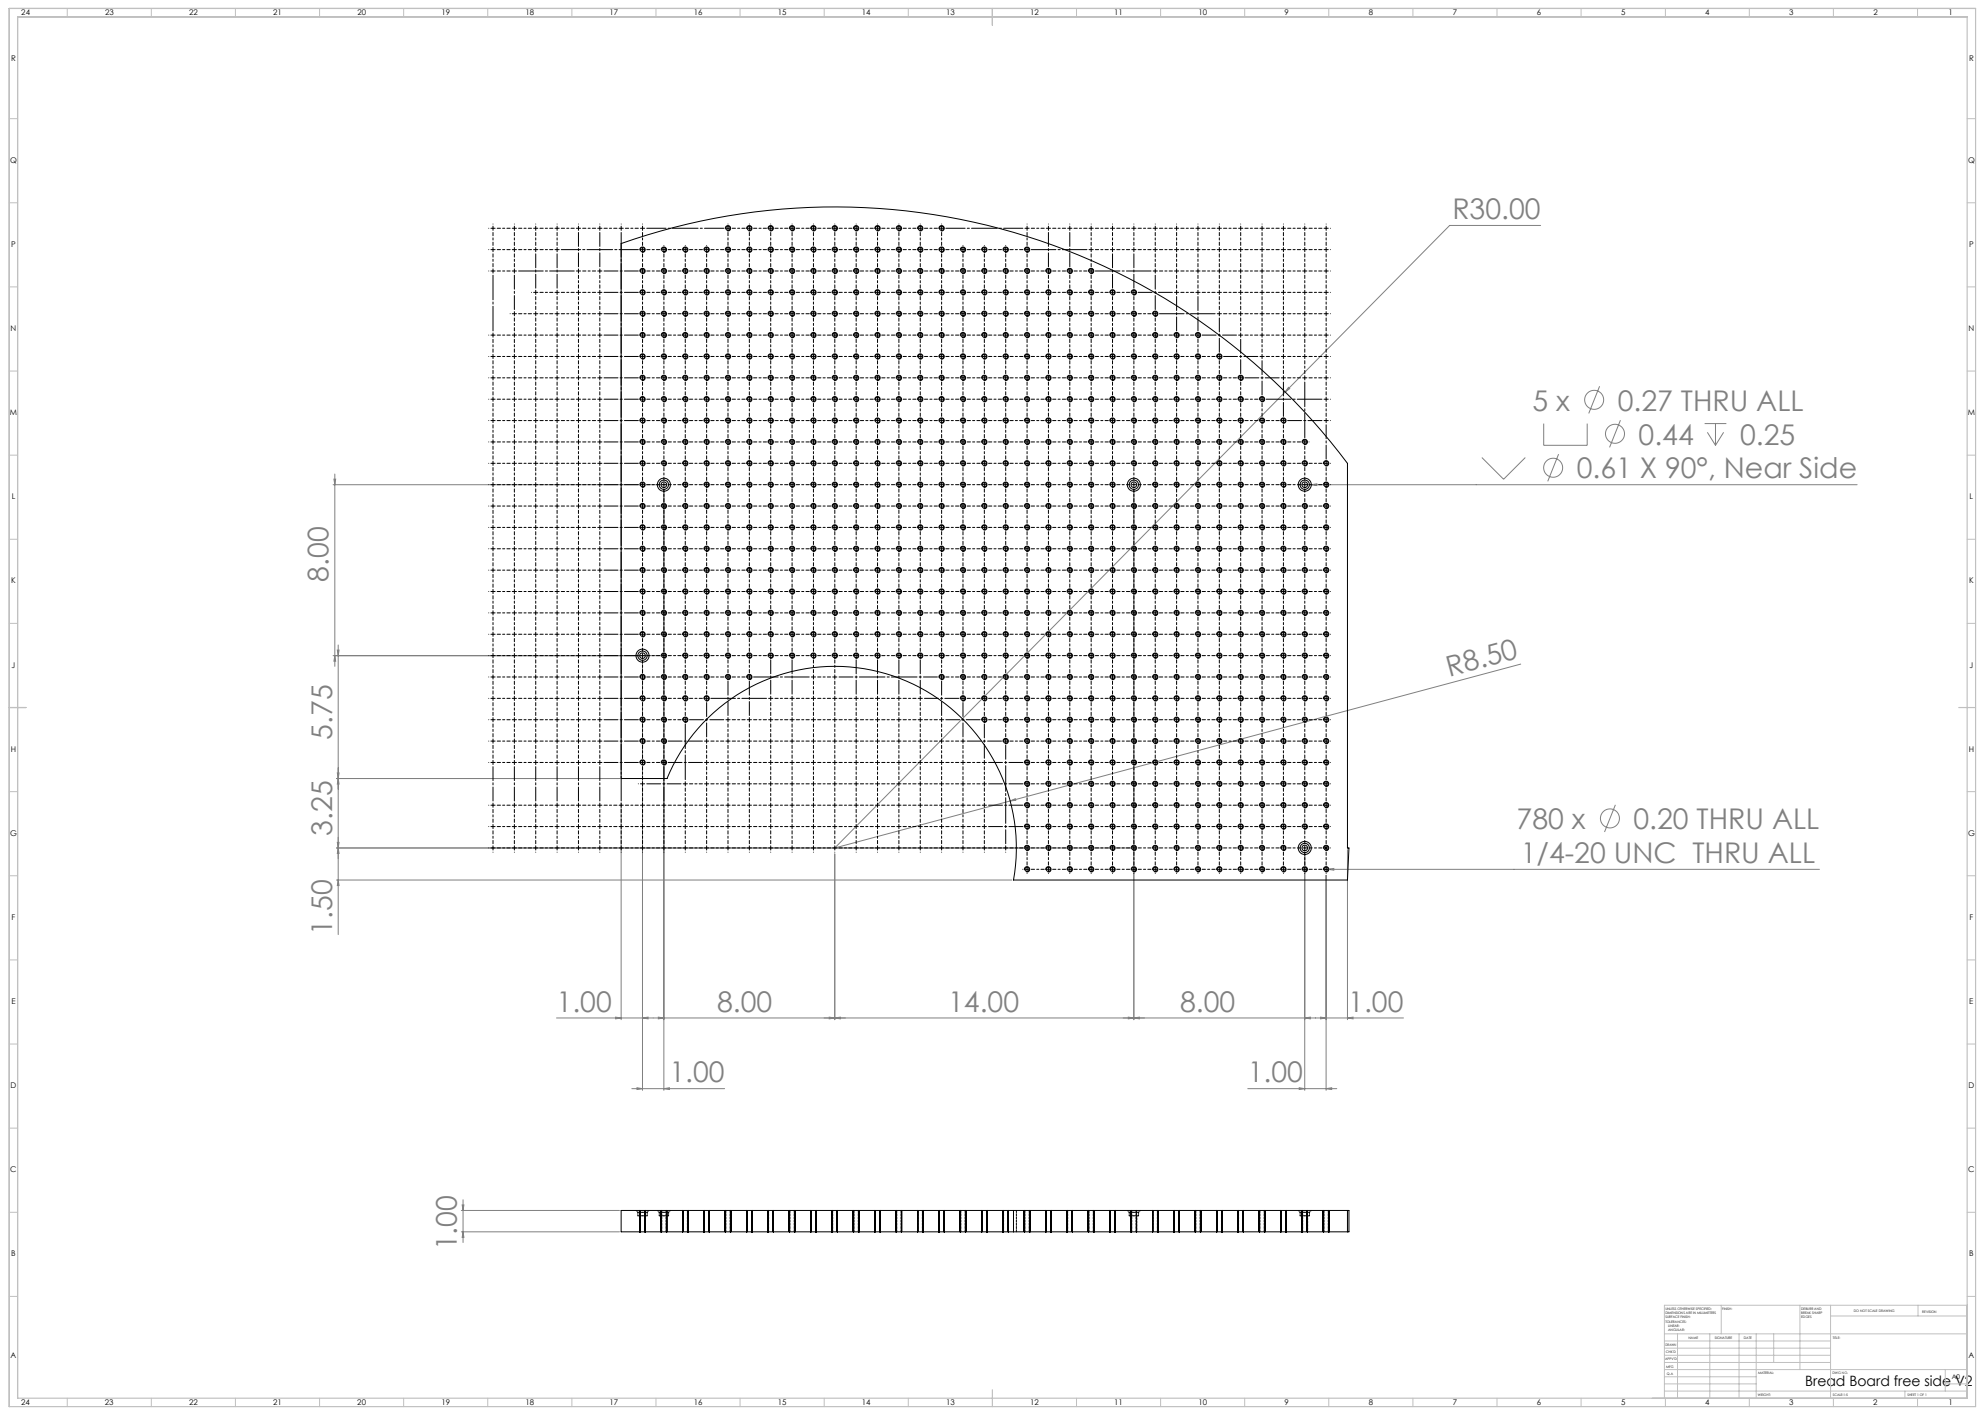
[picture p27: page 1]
0.27 THRU ALL; 0.44 0.25 0.61 X 90°, Near Side; 0.20 THRU ALL; FINISH:; DEBURR AND; BREAK SHARP; DO NOT SCALE DRAWING; REVISION; SCALE:1:5; SHEET 1 OF 1

1/4-20 UNC THRU ALL

UNLESS OTHERWISE SPECIFIED:
DIMENSIONS ARE IN MILLIMETERS
SURFACE FINISH:
TOLERANCES:
LINEAR:
ANGULAR:

NAME | SIGNATURE | DATE | | | | TITLE:

DRAWN
CHK'D
APPV'D
MFG
Q.A | | | | MATERIAL: Bread Board free side V2 | DWG NO. | A0

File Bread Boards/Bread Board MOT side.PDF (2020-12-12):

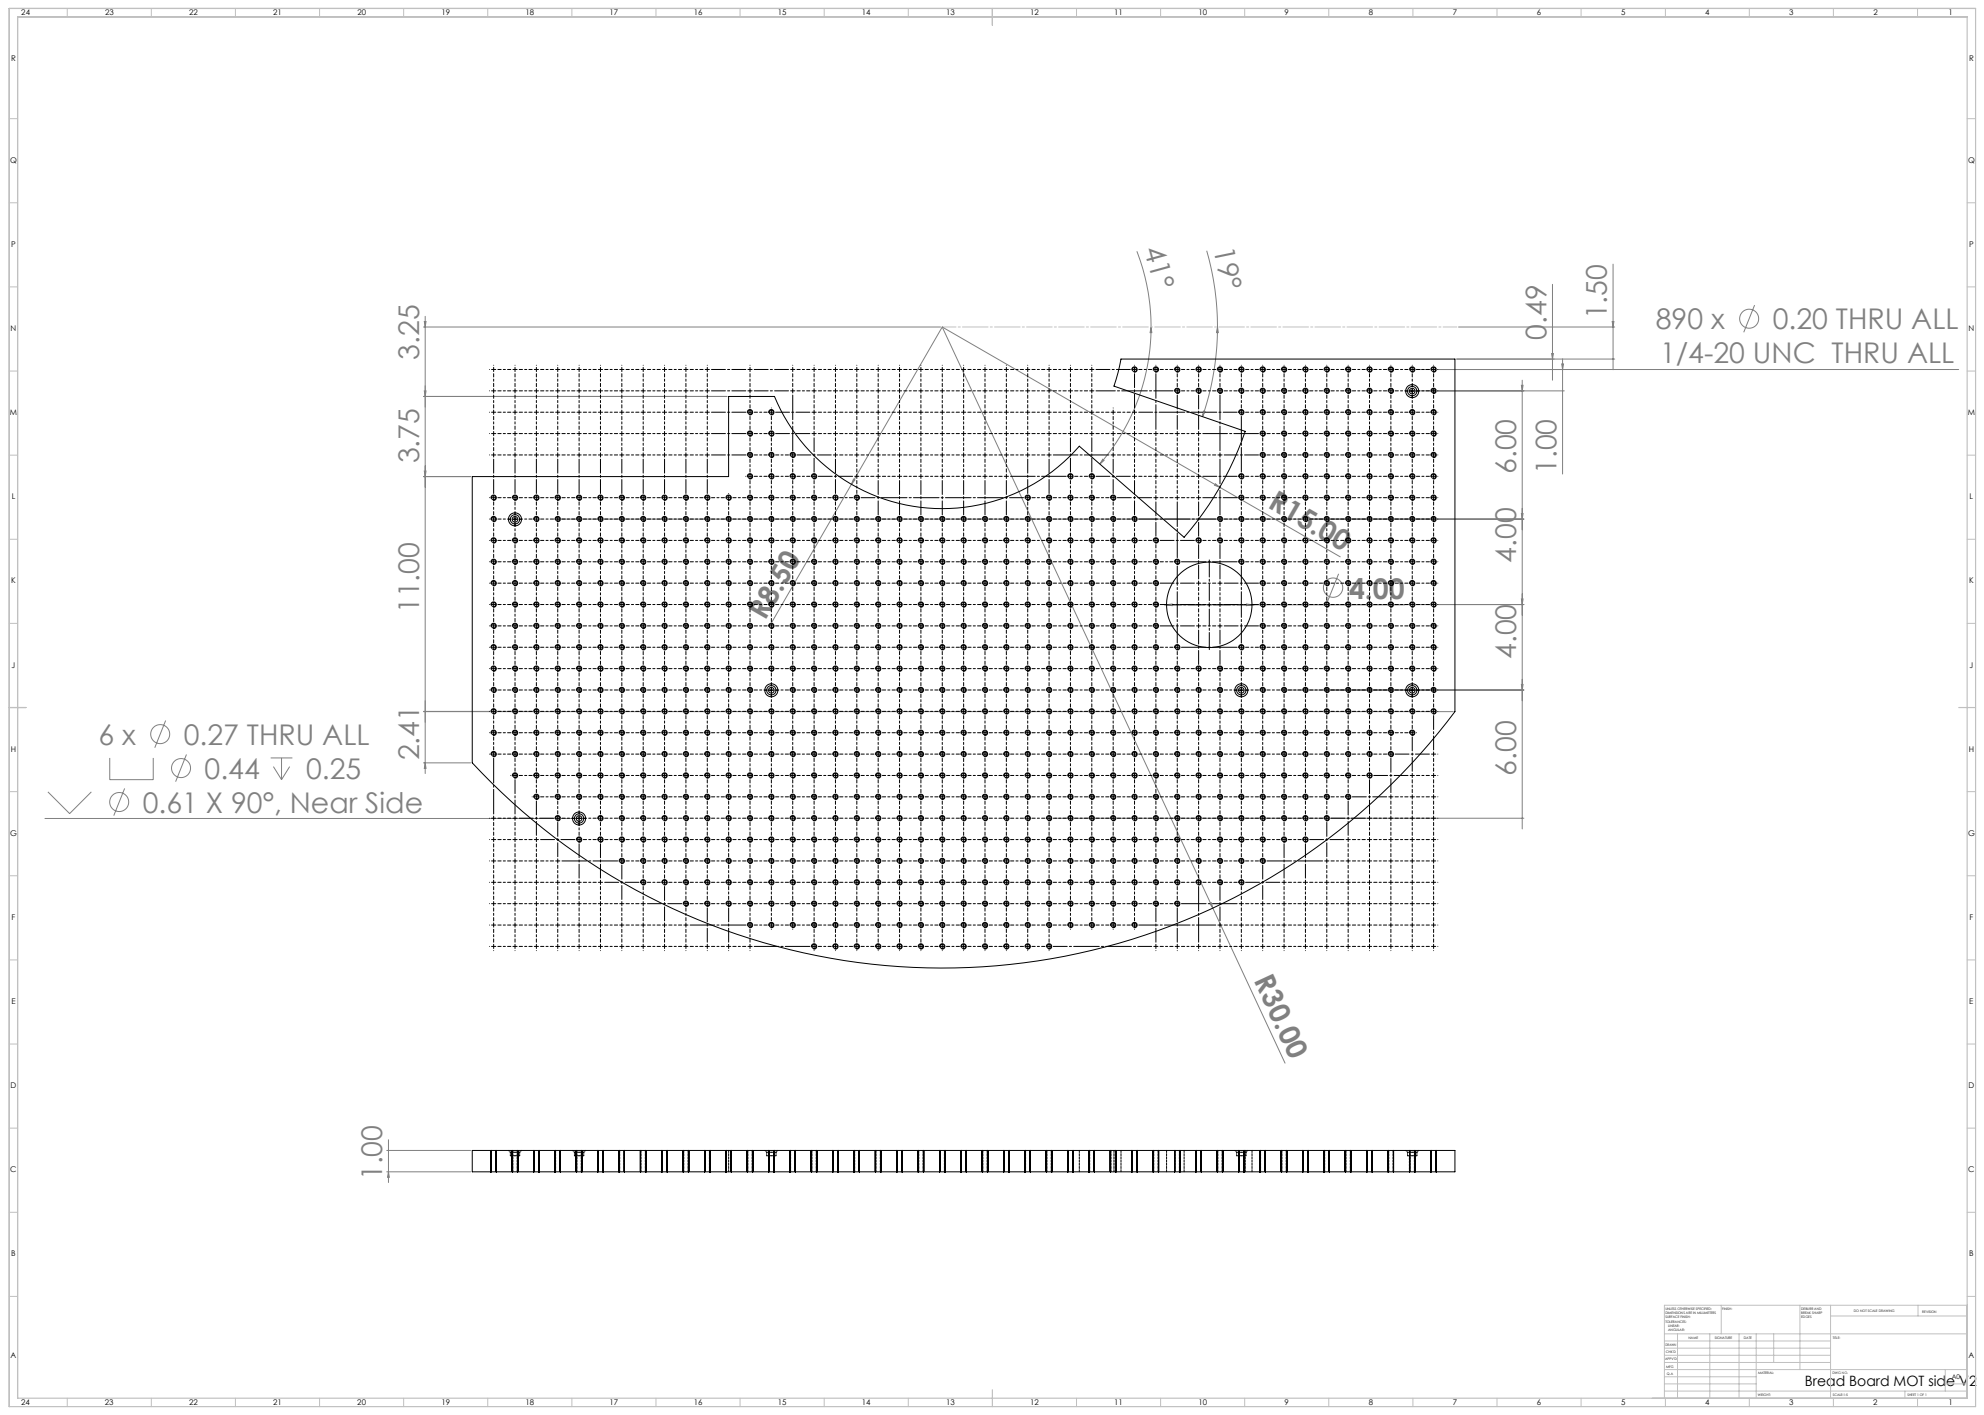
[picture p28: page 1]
0.20 THRU ALL; 0.27 THRU ALL; 0.61 X 90°, Near Side3.75 11.00 2.41; FINISH:; DEBURR AND; BREAK SHARP; DO NOT SCALE DRAWING; REVISION; SCALE:1:5; SHEET 1 OF 1

1/4-20 UNC THRU ALL

UNLESS OTHERWISE SPECIFIED:
DIMENSIONS ARE IN MILLIMETERS
SURFACE FINISH:
TOLERANCES:
LINEAR:
ANGULAR:

NAME | SIGNATURE | DATE | | | | TITLE:

DRAWN
CHK'D
APPV'D
MFG
Q.A | | | | MATERIAL: | DWG NO. | A0

Bread Board MOT side V2

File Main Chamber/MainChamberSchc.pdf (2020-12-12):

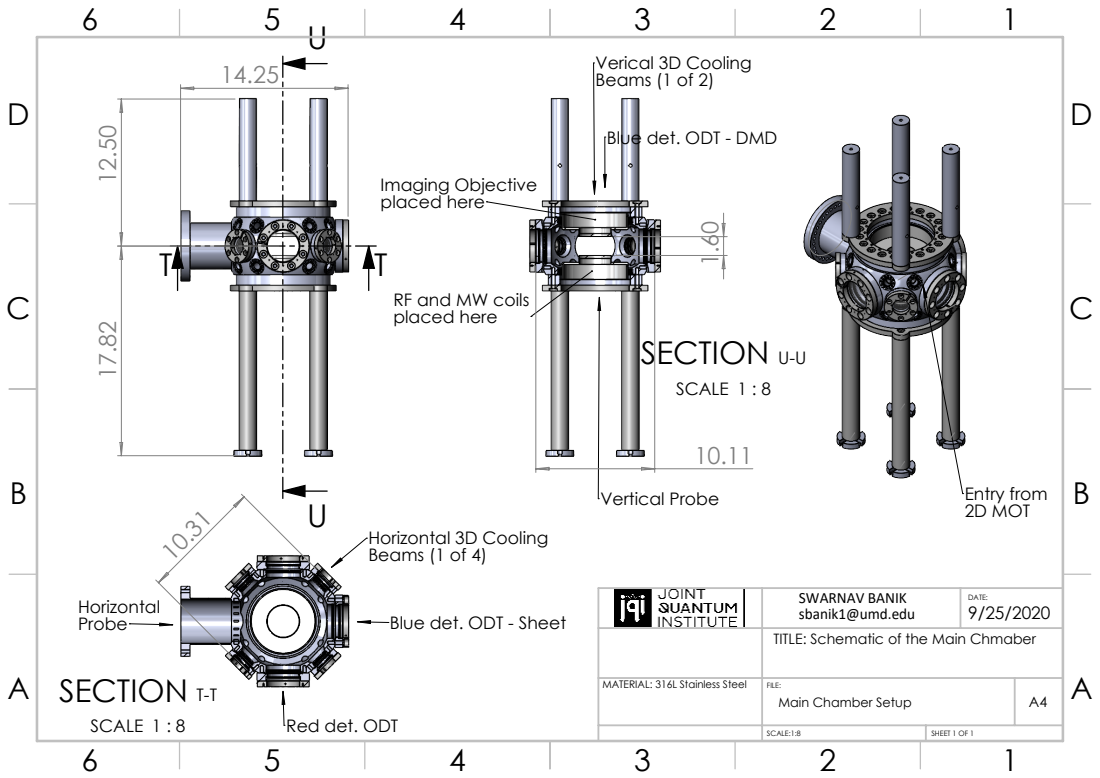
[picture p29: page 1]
SECTION T-T; SCALE 1 : 8; Horizontal 3D Cooling Beams (1 of 4); SECTION U-U; Verical 3D Cooling Beams (1 of 2); Vertical Probe; Imaging Objective placed here; Entry from 2D MOT; SWARNAV BANIK

Blue det. ODT - DMD

RF and MW coils
placed here

Blue det. ODT - Sheet

TITLE: Schematic of the Main Chmaber

MATERIAL: 316L Stainless Steel | FILE: Main Chamber Setup | A4

Red det. ODT

SCALE:1:8 | SHEET 1 OF 1

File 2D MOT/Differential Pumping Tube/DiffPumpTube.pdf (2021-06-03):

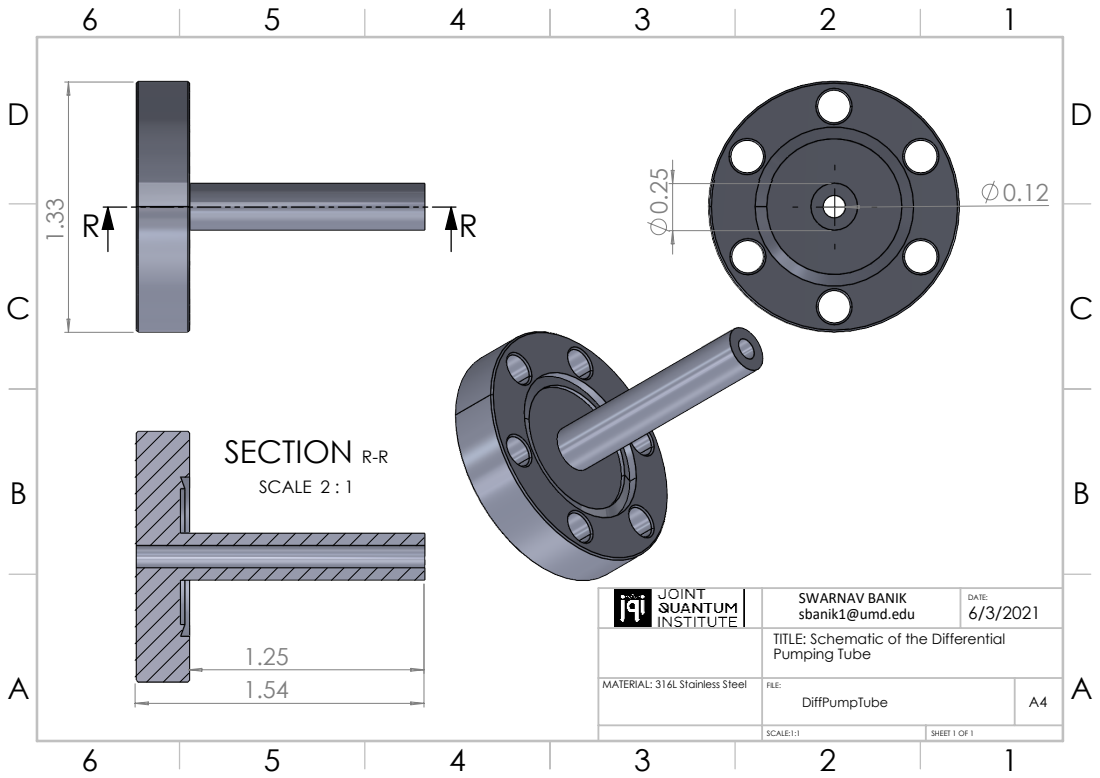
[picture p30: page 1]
SECTION R-R; SCALE 2 : 1

SWARNAV BANIK sbanik1@umd.edu | DATE: 6/3/2021

TITLE: Schematic of the Differential Pumping Tube

MATERIAL: 316L Stainless Steel | FILE: DiffPumpTube | A4

SCALE:1:1 | SHEET 1 OF 1

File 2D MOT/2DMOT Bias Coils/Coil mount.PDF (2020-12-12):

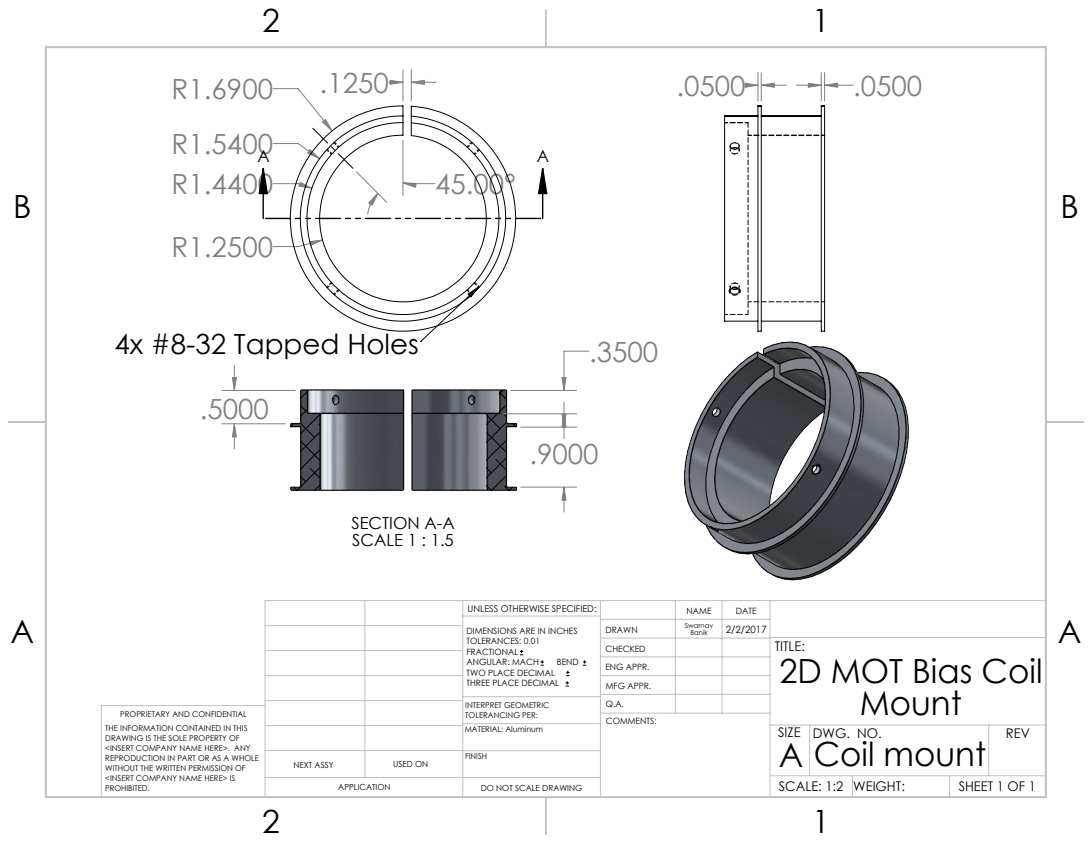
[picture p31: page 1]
4x #8-32 Tapped Holes; SECTION A-A SCALE 1 : 1.5

UNLESS OTHERWISE SPECIFIED: | | NAME | DATE
DIMENSIONS ARE IN INCHES TOLERANCES: 0.01 FRACTIONAL ANGULAR: MACH BEND TWO PLACE DECIMAL THREE PLACE DECIMAL | DRAWN | Banik | 2/2/2017 Swarnav

CHECKED | | | TITLE: 2D MOT Bias Coil Mount

ENG APPR.
MFG APPR.

INTERPRET GEOMETRIC TOLERANCING PER: | Q.A.
MATERIAL: Aluminum | | SIZE A | DWG. NO. Coil mount | REV

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

NEXT ASSY | USED ON | FINISH

APPLICATION | DO NOT SCALE DRAWING | | SCALE: 1:2 | WEIGHT: | SHEET 1 OF 1

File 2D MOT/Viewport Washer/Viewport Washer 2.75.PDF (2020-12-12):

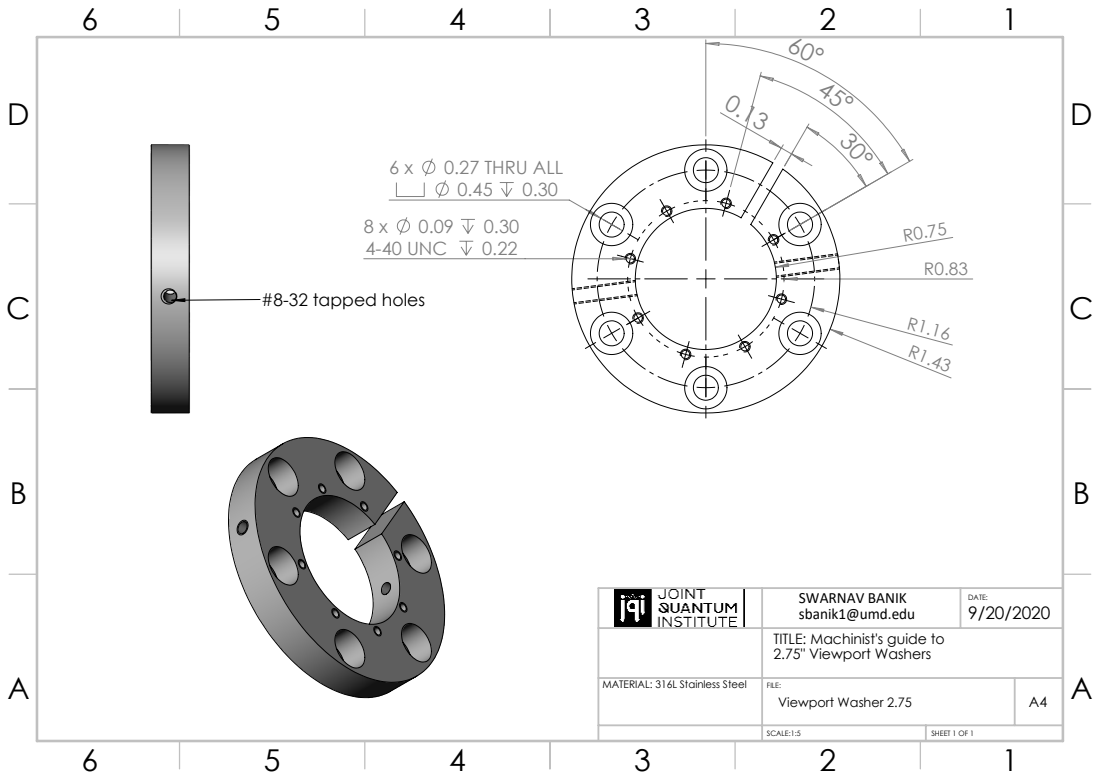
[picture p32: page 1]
0.27 THRU ALL; 4-40 UNC; #8-32 tapped holes

SWARNAV BANIK sbanik1@umd.edu | DATE: 9/20/2020

TITLE: Machinist's guide to 2.75" Viewport Washers

MATERIAL: 316L Stainless Steel | FILE: Viewport Washer 2.75 | A4

SCALE:1:5 | SHEET 1 OF 1

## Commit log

2021-06-03 updated Diff. Pumping tube
    [DiffPumpTube.SLDDRW, DiffPumpTube.SLDPRT]
2021-06-03 diff pumping tube
    [DiffPumpTube.SLDDRW]
